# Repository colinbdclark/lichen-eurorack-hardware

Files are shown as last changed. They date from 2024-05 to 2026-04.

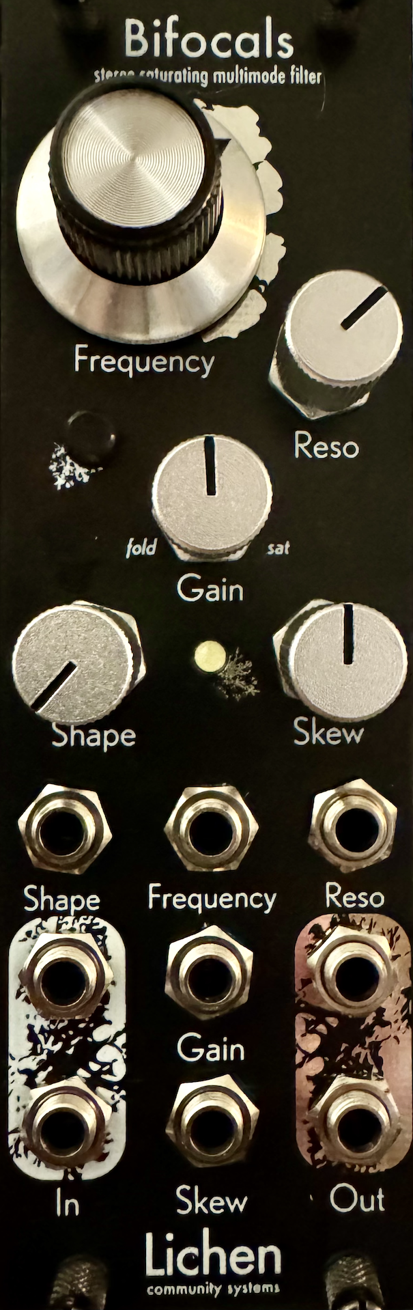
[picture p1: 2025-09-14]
bifocals-filter/bifocals photo small.png

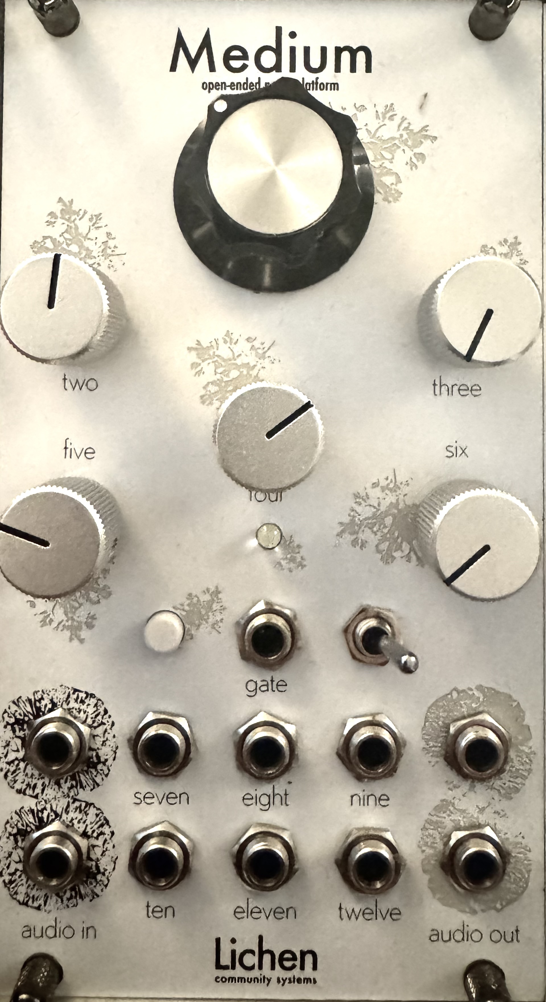
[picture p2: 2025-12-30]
lichen-medium/lichen-medium.jpg

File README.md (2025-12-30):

# Lichen Community Systems Eurorack Hardware Designs

A collection hardware schematics and PCB designs for Lichen Community Systems' experimental Eurorack modules. They were created with KiCad.

## License

These designs are Copyright 2023-5, Colin Clark. They are shared under the [Creative Commons Attribution Non-Commercial Share Alike 4.0](https://creativecommons.org/licenses/by-nc-sa/4.0/) license.

### Symbols and Footprints Library

The Lichen Kicad [symbols and footprints libraries](Lichen.pretty) were largely derived from KiCAD library symbols, and are made available under the same license:
https://kicad.org/libraries/license/

licensed under the Creative Commons CC-BY-SA 4.0 License
(https://creativecommons.org/licenses/by-sa/4.0/legalcode), with the following
exception:

To the extent that the creation of electronic designs that use
'Licensed Material' can be considered to be 'Adapted Material', then the
copyright holder waives article 3 of the license with respect to these designs
and any generated files which use data provided as part of the
'Licensed Material'.

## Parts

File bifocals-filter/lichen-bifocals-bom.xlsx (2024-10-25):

Quantity | Component | Rating | Manufacturer | Manufacturer Part Number | Vendor | Vendor Part Number | Unit Price | Currency | CAD Price | Module Price | Minimum Quantity | URL
1 | Daisy Patch Submodule |  | Electrosmith |  | Electrosmith |  | 25.2000 | USD | $34.08 | $34.08 |  | https://electro-smith.com/products/patch-submodule
2 | 2.54mm 2x5 10P pin header |  |  |  | Thonk |  | £0.114 | GBP | $0.21 | $0.42 | 10 | https://www.thonk.co.uk/shop/eurorack-diy-essentials/
6 | 2.54mm 2x5 10P pin socket |  | Sullins | PPTC052LFBN-RC | Digikey | S6105-ND | 0.5860 | CAD | $0.59 | $3.52 | 10 | https://www.digikey.ca/en/products/detail/sullins-connector-solutions/PPTC052LFBN-RC/807243
1 | 2.54mm 2x5 10P shrouded Eurorack power header |  | ULO Group | BHD10PHZT | Tayda | A-2939 | 0.1400 | USD | $0.19 | $0.19 |  | https://www.taydaelectronics.com/10-pin-box-header-connector-2-54mm.html
2 | 11mm M2 hex standoff |  | Würth | 970100244 | Digikey | 732-12845-ND | 0.5190 | CAD | $0.52 | $1.04 | 10 | https://www.digikey.ca/en/products/detail/würth-elektronik/970100244/9488549
4 | 6mm M2 screws |  | Essentra | 50M020040P006 | Digikey | 145-50M020040P006-ND | 0.0822 | CAD | $0.08 | $0.33 | 100 | https://www.digikey.ca/en/products/detail/essentra-components/50M020040P006/11639321
4 | 9mm vertical T18 potentiometer | 10K | Alpha | RD901F-40-15K-B10K | Thonk |  | £1.20 | GBP | $2.17 | $8.68 | 50 | https://www.thonk.co.uk/shop/alpha-9mm-pots-vertical-t18/
1 | 9mm vertical T18 potentiometer center detent | 10K | Alpha | RD901F-40-15K-B10K | Thonk |  | £1.82 | GBP | $3.29 | $3.29 | 10 | https://www.thonk.co.uk/shop/alpha-9mm-pots-vertical-t18/
1 | 6x2.8mm tactile switch | 250G | E-Switch | TL1105SPF250Q | Digikey | EG1862-ND | 0.3370 | CAD | $0.34 | $0.34 | 10 | https://www.digikey.ca/en/products/detail/e-switch/tl1105spf250q/271559
1 | Black switch cap |  | E-Switch | 1RBLK | Digikey | EG1882-ND | 0.2200 | CAD | $0.22 | $0.22 | 10 | https://www.digikey.ca/en/products/detail/e-switch/1RBLK/271579
1 | 3mm white LED |  |  |  | Tayda | A-2226 | 0.0400 | USD | $0.05 | $0.05 | 1 | https://www.taydaelectronics.com/led-3mm-white-water-clear-ultra-bright.html
9 | Thonkiconn mono 3.5mm audio jack |  | WQP | WQP518MA | Thonk |  | £0.27 | GBP | $0.49 | $4.41 | 100 | https://www.thonk.co.uk/shop/thonkiconn/
9 | Hex nuts for jacks |  |  |  | Thonk |  | £0.0338 | GBP | $0.06 | $0.55 | 50 | https://www.thonk.co.uk/shop/thonkiconn/
1 | Power PCB |  |  |  | JLCPCB |  | 1.3700 | USD | $1.85 | $1.85 | 5
1 | Control PCB |  |  |  | JLCPCB |  | 1.3500 | USD | $4.57 | $1.83 | 5
1 | Aluminium front panel |  |  |  | JLCPCB |  | 1.6320 | USD | $2.21 | $2.21 | 5
Total | (without shipping, tax, duty, brokerage fees etc.)
$63.00
 | PCBWay 2mm aluminum front panel black | 3.67 USD/5 CAD

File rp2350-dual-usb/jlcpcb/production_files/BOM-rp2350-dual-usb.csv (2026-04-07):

Comment | Designator | Footprint | LCSC | Quantity
1K | R16,R2,R5 | R_0402_1005Metric | C11702 | 3
100nF | C21 | C_0603 | C14663 | 1
15pF | C4,C5 | C_0402_1005Metric_small_pads | C1548 | 2
Conn_01x03_MountingPin | J1 | JST_SH_SM03B-SRSS-TB_1x03-1MP_P1.00mm_Horizontal | C160403 | 1
USB_C_Receptacle_USB2.0_16P | J2,J3 | USB_C_Receptacle_HRO_TYPE-C-31-M-12_Overhanging | C165948 | 2
4.7uF | C8 | C_0805 | C1779 | 1
12MHz | Y1 | Crystal_SMD_3225-4Pin_3.2x2.5mm | C20625731 | 1
Yellow | D1 | LED_0805_2012Metric_Pad1.15x1.40mm_HandSolder | C2296 | 1
Green | D2 | LED_0805_2012Metric_Pad1.15x1.40mm_HandSolder | C2297 | 1
5.1K | R7,R8 | R_0603 | C23186 | 2
4.7uF | C10,C3,C7,C9 | C_0402_1005Metric_small_pads | C23733 | 4
10R | R12 | R_0402_1005Metric | C25077 | 1
220R | R13,R14 | R_0402_1005Metric | C25091 | 2
27R | R17,R18,R3,R4 | R_0402_1005Metric | C25100 | 4
33R | R1,R11 | R_0402_1005Metric | C25105 | 2
470R | R15 | R_0402_1005Metric | C25117 | 1
100K | R19 | R_0402_1005Metric | C25741 | 1
1.5K | R6 | R_0402_1005Metric | C25867 | 1
1uF | C2 | C_0805 | C28323 | 1
100nF | C1,C11,C12,C13,C14,C15,C16,C17,C18,C19,C20,C6 | C_0402_1005Metric_small_pads | C307331 | 12
RP2354_60QFN | U2 | RP2350-QFN-60-1EP_7x7_P0.4mm_EP3.4x3.4mm_ThermalVias | C41378174 | 1
3.3uH | L1 | L_pol_2016 | C42411119 | 1
LDL1117-3.3 | U1 | SOT-223-3_TabPin2 | C435835 | 1
HCPL-0631 | U5 | SOIC-8_3.9x4.9mm_P1.27mm | C43949 | 1
TPS25810RVC | U6 | Texas_RVC0020A_WQFN-20-1EP_3x4mm_P0.5mm_EP1.6x2.6mm_ThermalVias | C473913 | 1
1P1T Switch | SW1 | SW_SPST_TS-1088-xR020 | C720477 | 1
USBLC6-2SC6 | U3,U4 | SOT-23-6 | C7519 | 2
TRS | J4,J5 | Jack_3.5mm_KoreanHropartsElec_PJ-320D-4A_Horizontal_Overhanging | C95562 | 2
47uF | C23,C24,C25 | C_1206_3216Metric | C96123 | 3
10uF | C22 | C_0603 | C96446 | 1

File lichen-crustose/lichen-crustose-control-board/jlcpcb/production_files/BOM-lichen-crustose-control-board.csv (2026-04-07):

Comment | Designator | Footprint | LCSC | Quantity
33pF C0G | C3,C4,C5,C6 | C_0603 | C1663 | 4
330pF C0G | C10,C7,C8,C9 | C_0603 | C1664 | 4
1K | R15,R16,R33,R34 | R_0603 | C21190 | 4
5.1K | R10,R13,R14,R9 | R_0603 | C23186 | 4
100K | R1,R17,R18,R19,R2,R20,R21,R22,R23,R24,R25,R26,R27,R28,R29,R3,R30,R5,R6,R7,R8 | R_0603 | C25803 | 21
10K | R11,R12,R31,R32,R35,R36,R37,R38,R39,R4,R40 | R_0603 | C25804 | 11
100nF | C11,C12,C13,C14,C16,C17,C18,C19 | C_0402_1005Metric_small_pads | C307331 | 8
100nF Film | C1,C2 | C_1210 | C569766 | 2
TL074 | OP1,OP2,OP3,OP4 | SOIC-14_3.9x8.7mm_P1.27mm | C6964 | 4

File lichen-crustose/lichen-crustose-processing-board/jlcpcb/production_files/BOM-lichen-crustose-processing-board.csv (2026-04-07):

Comment | Designator | Footprint | LCSC | Quantity
FerriteBead_0603_2A | L1,L2 | R_0603 | C14709 | 2
39K | R1 | R_0603 | C23153 | 1
10K | R2 | R_0603 | C25804 | 1
10uF | C1,C2,C4,C5,C6,C7 | C_0805 | C440198 | 6
Schottky | D1,D2 | D_SMA_Handsoldering | C8678 | 2

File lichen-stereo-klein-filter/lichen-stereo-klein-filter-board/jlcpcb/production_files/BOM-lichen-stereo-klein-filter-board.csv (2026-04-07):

Comment | Designator | Footprint | LCSC | Quantity
10uF | C15,C16,C27,C28,C29,C30 | C_1206_3216Metric | C13585 | 6
FerriteBead_0603_2A | L1,L2 | R_0603 | C14709 | 2
1K | R16,R26,R33,R42 | R_0603 | C21190 | 4
15K | R50,R8 | R_0603 | C22809 | 2
27K | R13,R54 | R_0603 | C22967 | 2
2K | R24,R40 | R_0603 | C22975 | 2
68K | R10,R17,R51,R52 | R_0603 | C23231 | 4
100K | R1,R12,R18,R34,R49,R53 | R_0603 | C25803 | 6
10K | R55,R56 | R_0603 | C25804 | 2
100nF | C17,C18,C19,C20,C21,C22,C23,C24,C25,C26 | C_0402_1005Metric_small_pads | C307331 | 10
33K | R19,R20,R22,R25,R29,R30,R31,R32,R35,R36,R39,R41,R45,R46,R47,R48 | R_0603 | C4216 | 16
MMBD4148TW | D1,D2,D3,D4,D5,D6 | SOT-363_SC-70-6 | C5240652 | 6
1nF | C10,C11,C13,C14,C2,C3,C4,C6,C7,C9 | C_0805 | C569826 | 10
TL072 | U6 | SOIC-8_3.9x4.9mm_P1.27mm | C6961 | 1
TL074 | U2,U3,U4,U5 | SOIC-14_3.9x8.7mm_P1.27mm | C6964 | 4
02x07 Pins | J8 | PinHeader_2x07_P2.54mm_Vertical_SMD | C84004 | 1
Schottky | D7,D8 | D_SMA_Handsoldering | C8678 | 2

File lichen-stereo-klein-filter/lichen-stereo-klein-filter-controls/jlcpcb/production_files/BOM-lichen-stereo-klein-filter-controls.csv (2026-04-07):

Comment | Designator | Footprint | LCSC | Quantity
1K | R27,R43,R7 | R_0603 | C21190 | 3
12K | R11 | R_0603 | C22790 | 1
27K | R2 | R_0603 | C22967 | 1
2K | R23,R38 | R_0603 | C22975 | 2
100K | R14,R21,R28,R37,R44 | R_0603 | C25803 | 5
10K | R15,R3,R4,R5,R6,R9 | R_0603 | C25804 | 6
100nF | C31,C32 | C_0402_1005Metric_small_pads | C307331 | 2
TL074 | U1 | SOIC-14_3.9x8.7mm_P1.27mm | C6964 | 1
02x07 Socket | J7 | PinSocket_2x07_P2.54mm_Vertical_SMD | C84005 | 1

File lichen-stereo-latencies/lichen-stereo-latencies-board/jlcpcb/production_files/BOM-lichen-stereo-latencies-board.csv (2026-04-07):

Comment | Designator | Footprint | LCSC | Quantity
1K | R15,R19 | R_0402_1005Metric | C11702 | 2
FerriteBead_0603_2A | L1,L2 | R_0603 | C14709 | 2
33pF C0G | C5,C6 | C_0603 | C1663 | 2
100K | R1,R10,R11,R12,R13,R14,R16,R17,R18,R2,R20,R3,R4,R5,R6,R7,R8,R9 | R_0402_1005Metric | C25741 | 18
10K | R21 | R_0402_1005Metric | C25744 | 1
12K | R22 | R_0402_1005Metric | C25752 | 1
10uF | C7,C8 | C_0805 | C440198 | 2
TL074 | U1,U3,U5,U7 | SOIC-14_3.9x8.7mm_P1.27mm | C6964 | 4
Schottky | D1,D2 | D_SMA_Handsoldering | C8678 | 2

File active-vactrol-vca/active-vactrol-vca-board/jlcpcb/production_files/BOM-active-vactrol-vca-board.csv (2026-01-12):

Comment | Designator | Footprint | LCSC | Quantity
FerriteBead_0603_2A | L1,L2 | R_0603 | C14709 | 2
33pF C0G | C5,C8 | C_0603 | C1663 | 2
1k_0603 | R18,R9 | R_0603 | C21190 | 2
1R | R6,R7 | R_0603 | C22936 | 2
100k_0603 | R1,R10,R11,R12,R13,R17,R19,R2,R20,R3,R4,R5,R8 | R_0603 | C25803 | 13
10uF_0805_25V | C1,C2 | C_0805 | C440198 | 2
22uF_0805_25V | C3,C6 | C_0805 | C45783 | 2
AMS1117-5.0 | U7 | SOT-223-3_TabPin2 | C6187 | 1
TL072 | U1,U2,U3,U4 | SOIC-8_3.9x4.9mm_P1.27mm | C6961 | 4
Schottky | D1,D2 | D_SMA_Handsoldering | C8678 | 2

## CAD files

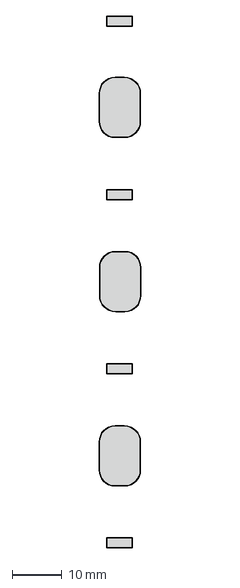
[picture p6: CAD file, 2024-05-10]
lichen-usb-extender/2 hp usb extender.dxf
8.35 x 107.1 mm

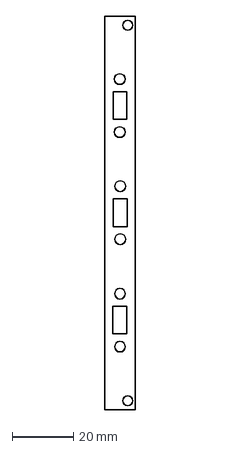
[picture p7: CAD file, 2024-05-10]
lichen-usb-extender/edge cuts - 2 hp usb extender.dxf
10.00 x 128.5 mm

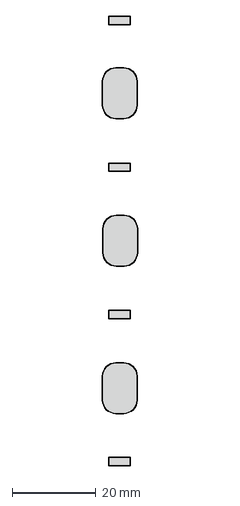
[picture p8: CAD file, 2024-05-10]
lichen-usb-extender/silkscreen - 2 hp usb extender.dxf
8.35 x 107.1 mm

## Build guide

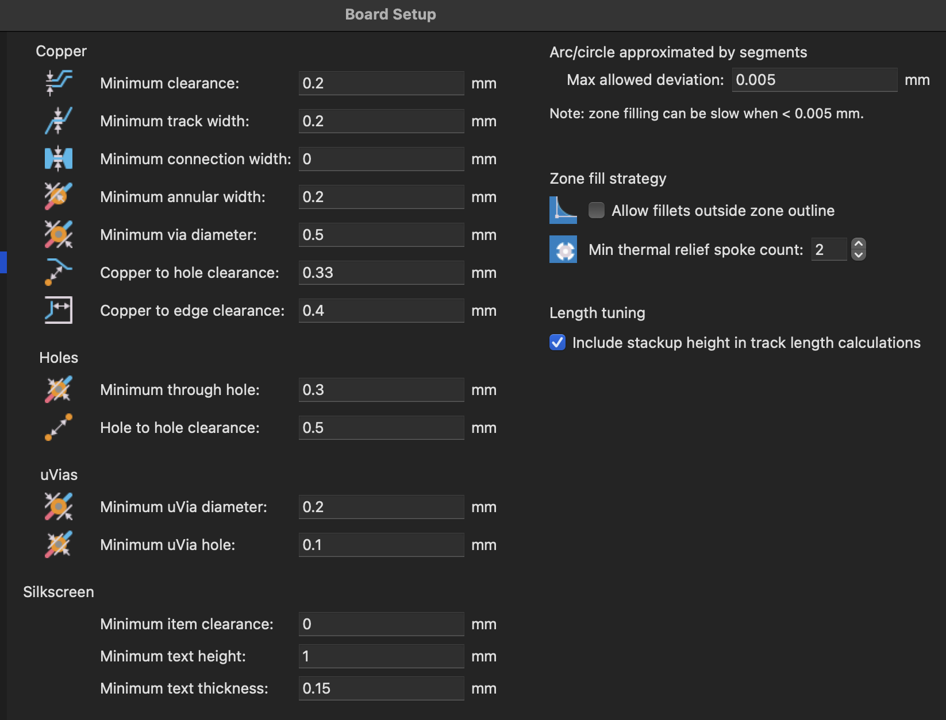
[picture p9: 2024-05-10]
kicad-setup/Board Setup Constraints.png

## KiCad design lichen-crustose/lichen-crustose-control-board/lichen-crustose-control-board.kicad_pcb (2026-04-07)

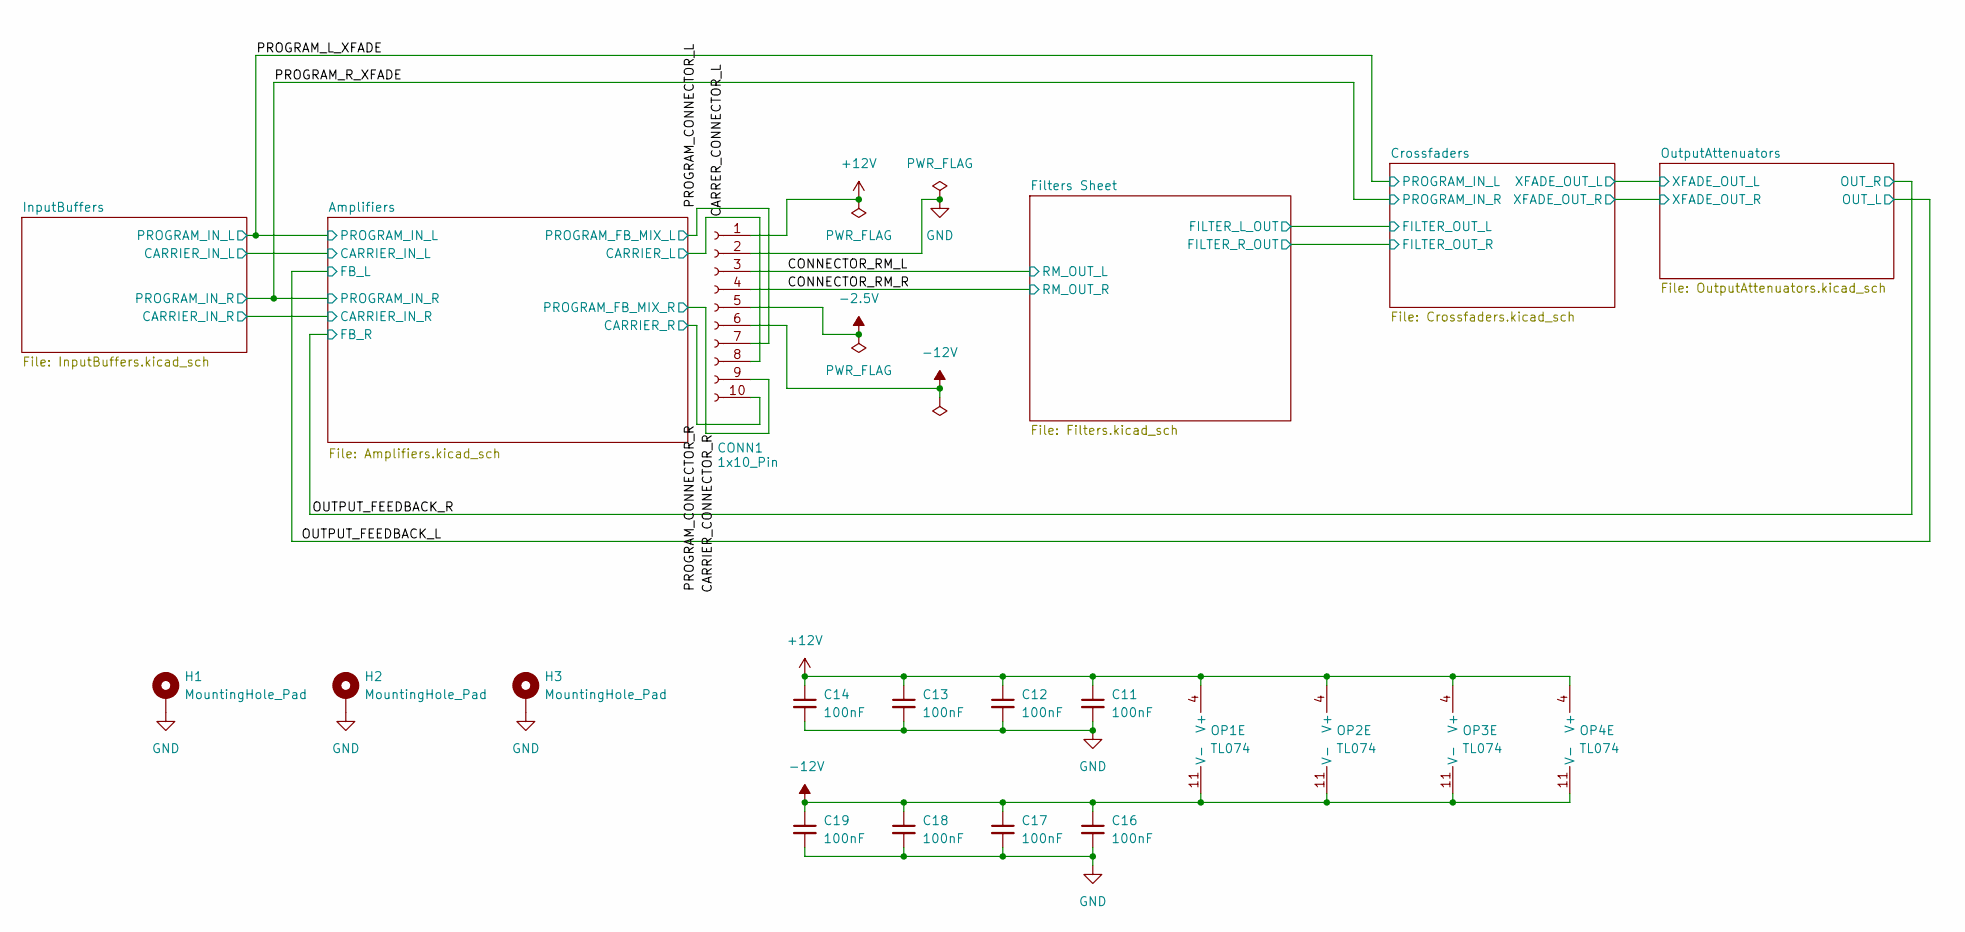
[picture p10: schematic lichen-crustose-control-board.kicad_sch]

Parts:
C11, C12, C13, C14, C16, C17, C18, C19: 100nF; C_0402_1005Metric_small_pads; Part Number CL05B104KB54PNC; LCSC C307331
CONN1: 1x10_Pin; PinHeader_1x10_P2.54mm_Vertical
H1, H2, H3: MountingHole_Pad; MountingHole_2.2mm_M2_Pad
OP1, OP2, OP3, OP4: TL074; SOIC-14_3.9x8.7mm_P1.27mm; Part Number TL074IDR; LCSC C6964

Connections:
+12V: C11.1, C12.1, C13.1, C14.1, CONN1.1, OP1.4 (V+), OP2.4 (V+), OP3.4 (V+), OP4.4 (V+)
-2.5V: CONN1.5; also elsewhere on the board
-12V: C16.1, C17.1, C18.1, C19.1, CONN1.6, OP1.11 (V-), OP2.11 (V-), OP3.11 (V-), OP4.11 (V-)
/CARRER_CONNECTOR_L: CONN1.8; also elsewhere on the board
/CARRIER_CONNECTOR_R: CONN1.9; also elsewhere on the board
/CONNECTOR_RM_L: CONN1.3; also elsewhere on the board
/CONNECTOR_RM_R: CONN1.4; also elsewhere on the board
/PROGRAM_CONNECTOR_L: CONN1.7; also elsewhere on the board
/PROGRAM_CONNECTOR_R: CONN1.10; also elsewhere on the board
GND: C11.2, C12.2, C13.2, C14.2, C16.2, C17.2, C18.2, C19.2, CONN1.2, H1.1, H2.1, H3.1; also elsewhere on the board

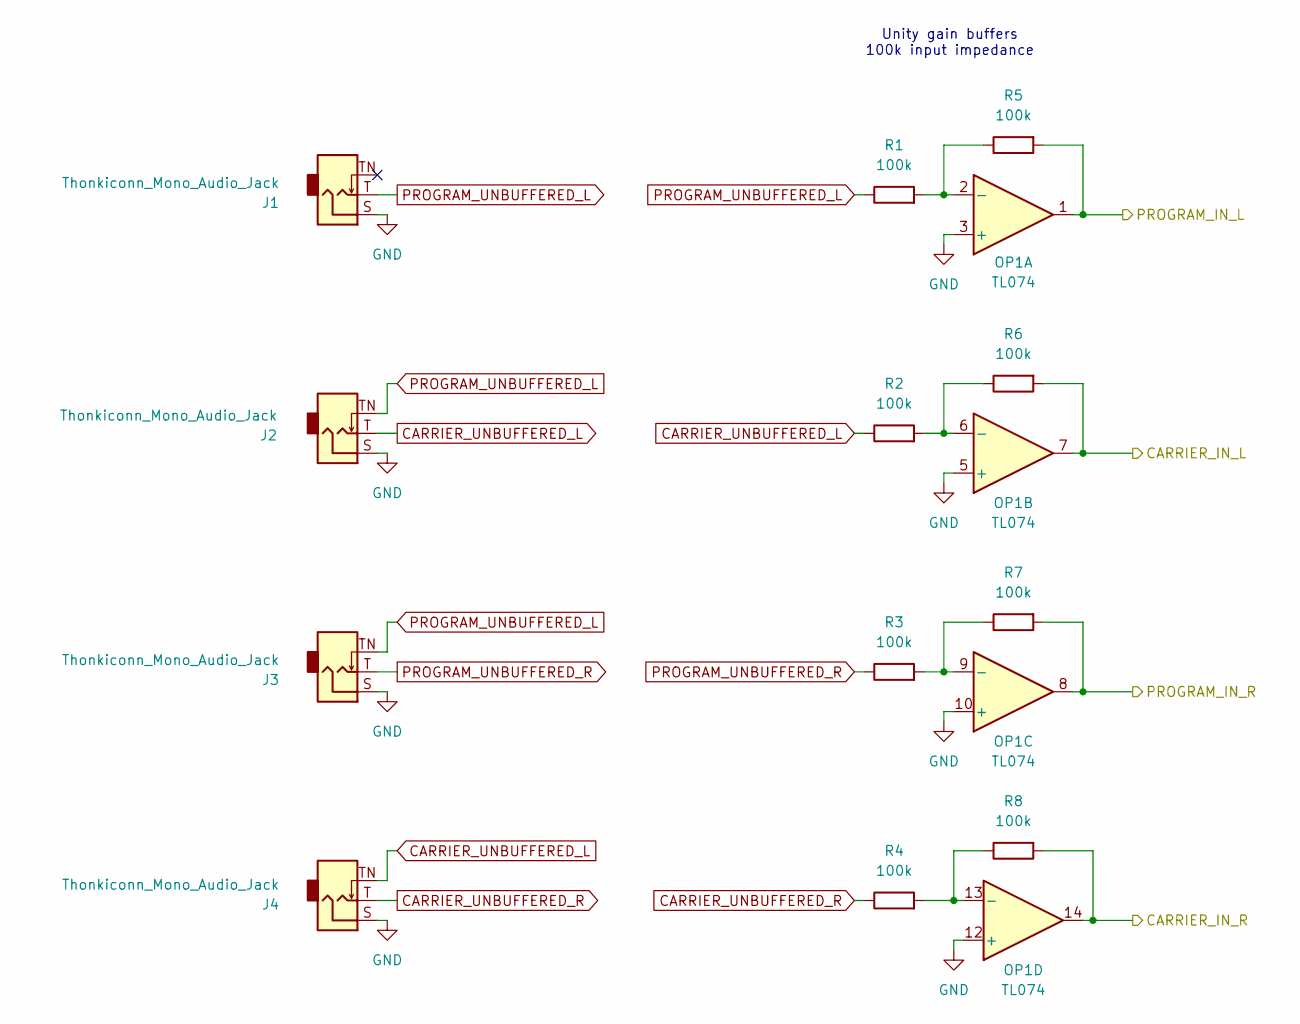
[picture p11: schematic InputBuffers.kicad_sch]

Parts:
J1, J2, J3, J4: Thonkiconn_Mono_Audio_Jack; Audio_Jack_Thonkiconn_Mono; Part Number WQP518MA/PJ398SM
OP1: TL074; SOIC-14_3.9x8.7mm_P1.27mm; Part Number TL074IDR; LCSC C6964
R1, R2, R3, R4, R5, R6, R7: 100K; R_0603; Part Number 0603WAF1003T5E; LCSC C25803
R8: 100K; R_0603; Part Number 0603WAF1003T5E; JLCPCB ID C25803

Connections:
/Amplifiers/CARRIER_IN_L: OP1.7, R6.2; also elsewhere on the board
/Amplifiers/CARRIER_IN_R: OP1.14, R8.2; also elsewhere on the board
/PROGRAM_L_XFADE: OP1.1, R5.2; also elsewhere on the board
/PROGRAM_R_XFADE: OP1.8, R7.2; also elsewhere on the board
CARRIER_UNBUFFERED_L: J2.T, J4.TN, R2.1
CARRIER_UNBUFFERED_R: J4.T, R4.1
GND: J1.S, J2.S, J3.S, J4.S, OP1.3 (+), OP1.5 (+), OP1.10 (+), OP1.12 (+); also elsewhere on the board
unnamed: OP1.2 (-), R1.2, R5.1
unnamed: OP1.6 (-), R2.2, R6.1
unnamed: OP1.9 (-), R3.2, R7.1
unnamed: OP1.13 (-), R4.2, R8.1
PROGRAM_UNBUFFERED_L: J1.T, J2.TN, J3.TN, R1.1
PROGRAM_UNBUFFERED_R: J3.T, R3.1

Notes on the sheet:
Unity gain buffers 100k input impedance

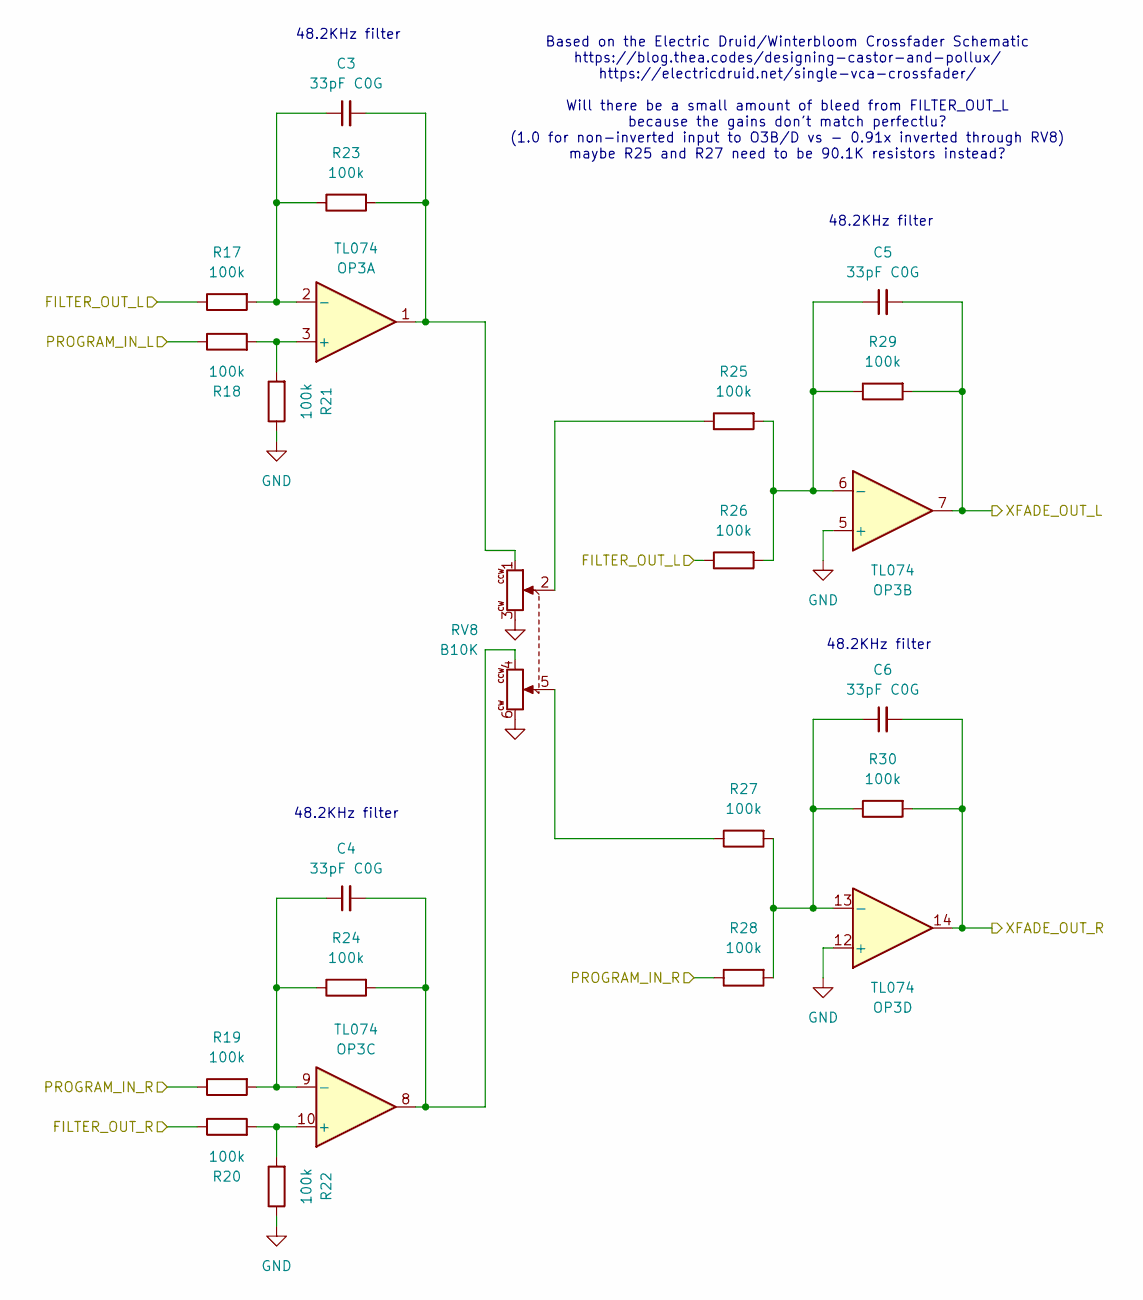
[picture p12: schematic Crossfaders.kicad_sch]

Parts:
C3, C4, C5, C6: 33pF C0G; C_0603; Part Number CL10C330JB8NNNC; LCSC C1663
OP3: TL074; SOIC-14_3.9x8.7mm_P1.27mm; Part Number TL074IDR; LCSC C6964
R17, R18, R19, R20, R21, R22, R23, R24, R25, R26, R27, R28, R29, R30: 100K; R_0603; Part Number 0603WAF1003T5E; LCSC C25803
RV8: B10K; Potentiometer_Alpha_RD902F-40-00D_Dual_Vertical; Part Number RD90F-40

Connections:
/Crossfaders/FILTER_OUT_L: R17.1, R26.1; also elsewhere on the board
/Crossfaders/FILTER_OUT_R: R20.1; also elsewhere on the board
/Crossfaders/XFADE_OUT_L: C5.2, OP3.7, R29.2; also elsewhere on the board
/Crossfaders/XFADE_OUT_R: C6.2, OP3.14, R30.2; also elsewhere on the board
/PROGRAM_L_XFADE: R18.1; also elsewhere on the board
/PROGRAM_R_XFADE: R19.1, R28.1; also elsewhere on the board
GND: OP3.5 (+), OP3.12 (+), R21.1, R22.1, RV8.3, RV8.6; also elsewhere on the board
unnamed: C3.2, OP3.1, R23.2, RV8.1
unnamed: C4.2, OP3.8, R24.2, RV8.4
unnamed: OP3.3 (+), R18.2, R21.2
unnamed: C3.1, OP3.2 (-), R17.2, R23.1
unnamed: C5.1, OP3.6 (-), R25.2, R26.2, R29.1
unnamed: OP3.10 (+), R20.2, R22.2
unnamed: C4.1, OP3.9 (-), R19.2, R24.1
unnamed: C6.1, OP3.13 (-), R27.2, R28.2, R30.1
unnamed: R25.1, RV8.2
unnamed: R27.1, RV8.5

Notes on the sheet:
Based on the Electric Druid/Winterbloom Crossfader Schematic https://blog.thea.codes/designing-castor-and-pollux/ https://electricdruid.net/single-vca-crossfader/ Will there be a small amount of bleed from FILTER_OUT_L because the gains don't match perfectlu? (1.0 for non-inverted input to O3B/D vs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
48.2KHz filter

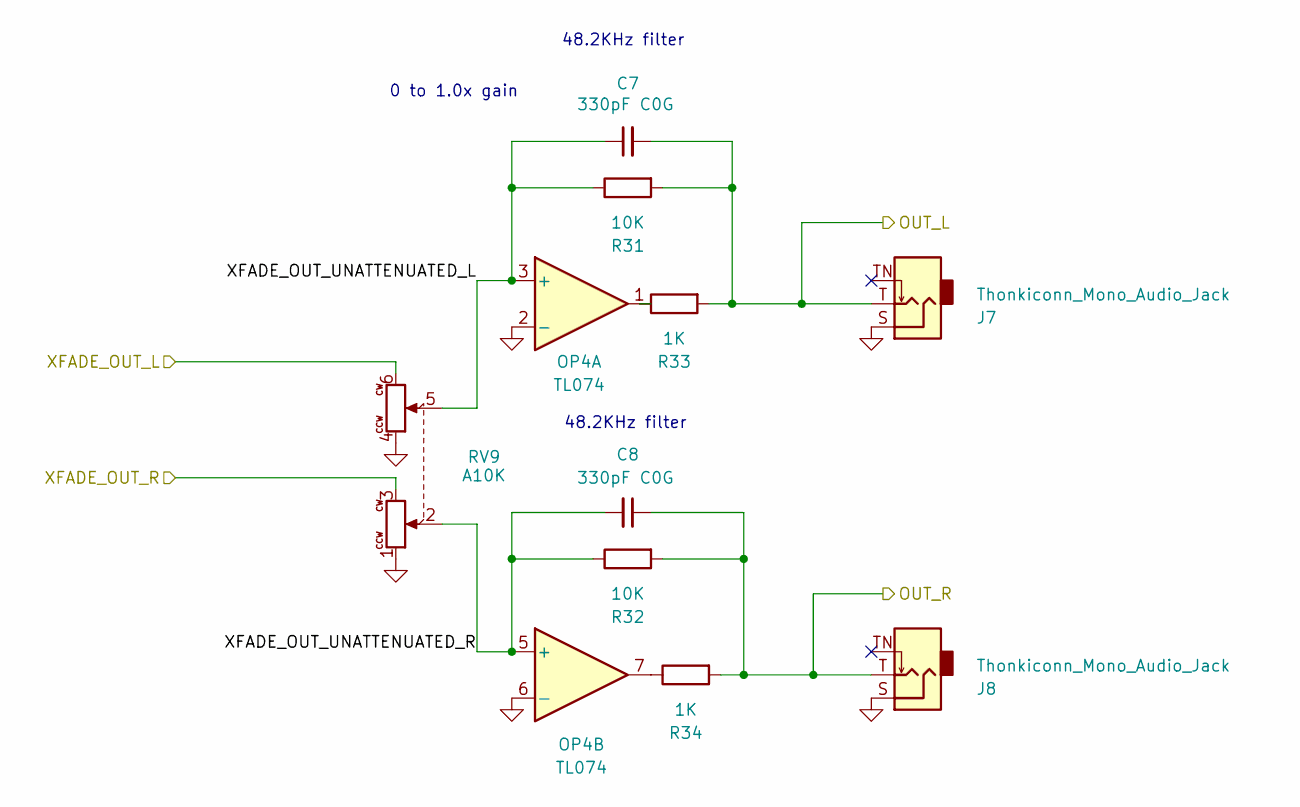
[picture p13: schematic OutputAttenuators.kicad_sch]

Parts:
C7, C8: 330pF C0G; C_0603; Part Number CL10C331JB8NNNC; LCSC C1664
J7, J8: Thonkiconn_Mono_Audio_Jack; Audio_Jack_Thonkiconn_Mono; Part Number WQP518MA/PJ398SM
OP4: TL074; SOIC-14_3.9x8.7mm_P1.27mm; Part Number TL074IDR; LCSC C6964
R31, R32: 10K; R_0603; Part Number 0603WAF1002T5E; LCSC C25804
R33, R34: 1K; R_0603; Part Number 0603WAF1001T5E; LCSC C21190
RV9: A10K; Potentiometer_Alpha_RD902F-40-00D_Dual_Vertical; Part Number RD90F-40

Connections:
/Crossfaders/XFADE_OUT_L: RV9.6; also elsewhere on the board
/Crossfaders/XFADE_OUT_R: RV9.3; also elsewhere on the board
/OUTPUT_FEEDBACK_L: C7.2, J7.T, R31.2, R33.2; also elsewhere on the board
/OUTPUT_FEEDBACK_R: C8.1, J8.T, R32.2, R34.2; also elsewhere on the board
/OutputAttenuators/XFADE_OUT_UNATTENUATED_L: C7.1, OP4.3 (+), R31.1, RV9.5
/OutputAttenuators/XFADE_OUT_UNATTENUATED_R: C8.2, OP4.5 (+), R32.1, RV9.2
GND: J7.S, J8.S, OP4.2 (-), OP4.6 (-), RV9.1, RV9.4; also elsewhere on the board
unnamed: OP4.1, R33.1
unnamed: OP4.7, R34.1

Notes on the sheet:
48.2KHz filter
0 to 1.0x gain

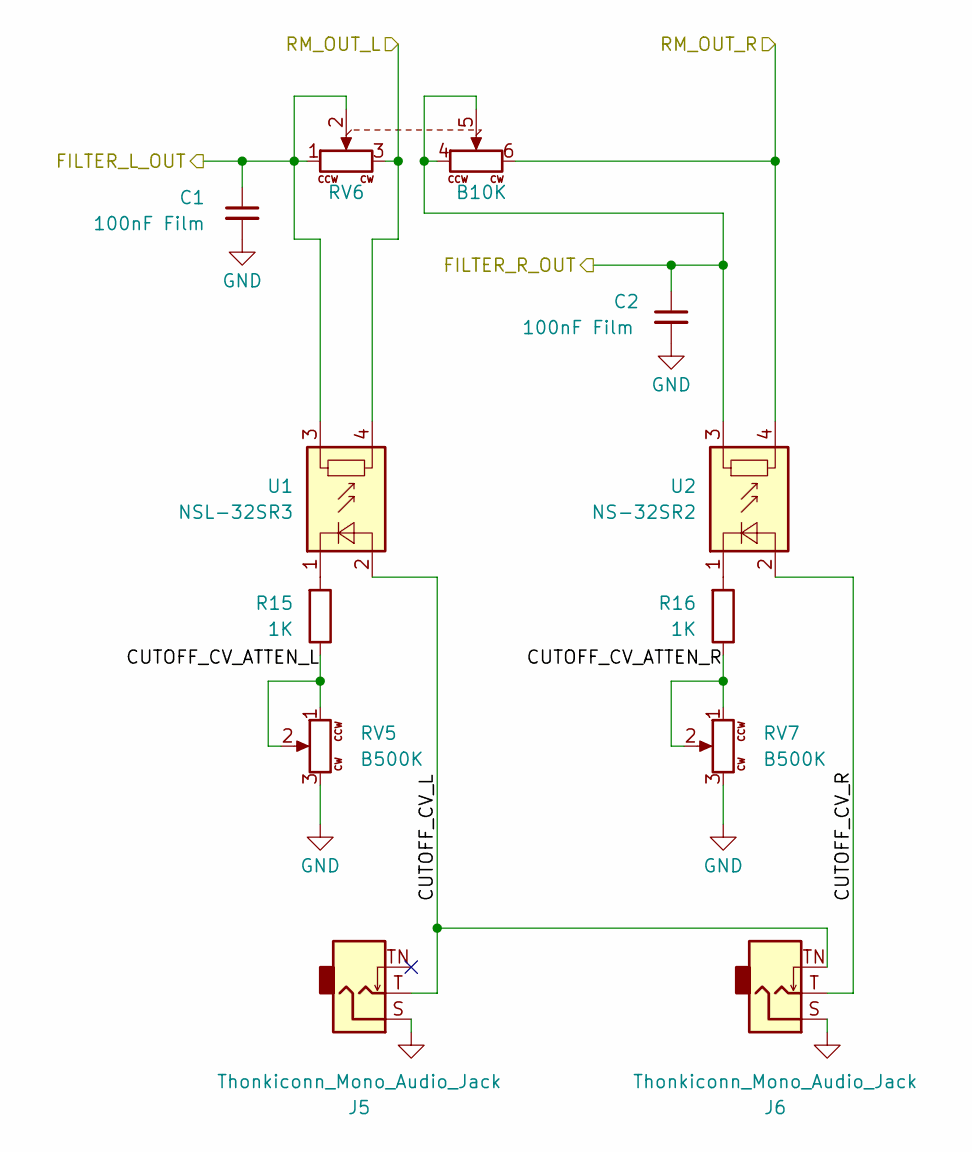
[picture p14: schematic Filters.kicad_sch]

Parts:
C1, C2: 100nF Film; C_1210; Part Number ECHU1C104GX5; LCSC C569766
J5, J6: Thonkiconn_Mono_Audio_Jack; Audio_Jack_Thonkiconn_Mono; Part Number WQP518MA/PJ398SM
R15, R16: 1K; R_0603; Part Number 0603WAF1001T5E; LCSC C21190
RV5, RV7: B500K; Potentiometer_Alpha_RD901_Eurorack; Part Number RD901F-40
RV6: B10K; Potentiometer_Alpha_RD902F-40-00D_Dual_Vertical; Part Number RD90F-40
U1: NSL-32SR3; NSL-32
U2: NS-32SR2; NSL-32

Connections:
/CONNECTOR_RM_L: RV6.3, U1.4; also elsewhere on the board
/CONNECTOR_RM_R: RV6.6, U2.4; also elsewhere on the board
/Crossfaders/FILTER_OUT_L: C1.1, RV6.1, RV6.2, U1.3; also elsewhere on the board
/Crossfaders/FILTER_OUT_R: C2.1, RV6.4, RV6.5, U2.3; also elsewhere on the board
/Filters Sheet/CUTOFF_CV_ATTEN_L: R15.1, RV5.1, RV5.2
/Filters Sheet/CUTOFF_CV_ATTEN_R: R16.1, RV7.1, RV7.2
/Filters Sheet/CUTOFF_CV_L: J5.T, J6.TN, U1.2 (+)
/Filters Sheet/CUTOFF_CV_R: J6.T, U2.2 (+)
GND: C1.2, C2.2, J5.S, J6.S, RV5.3, RV7.3; also elsewhere on the board
unnamed: R15.2, U1.1 (-)
unnamed: R16.2, U2.1 (-)

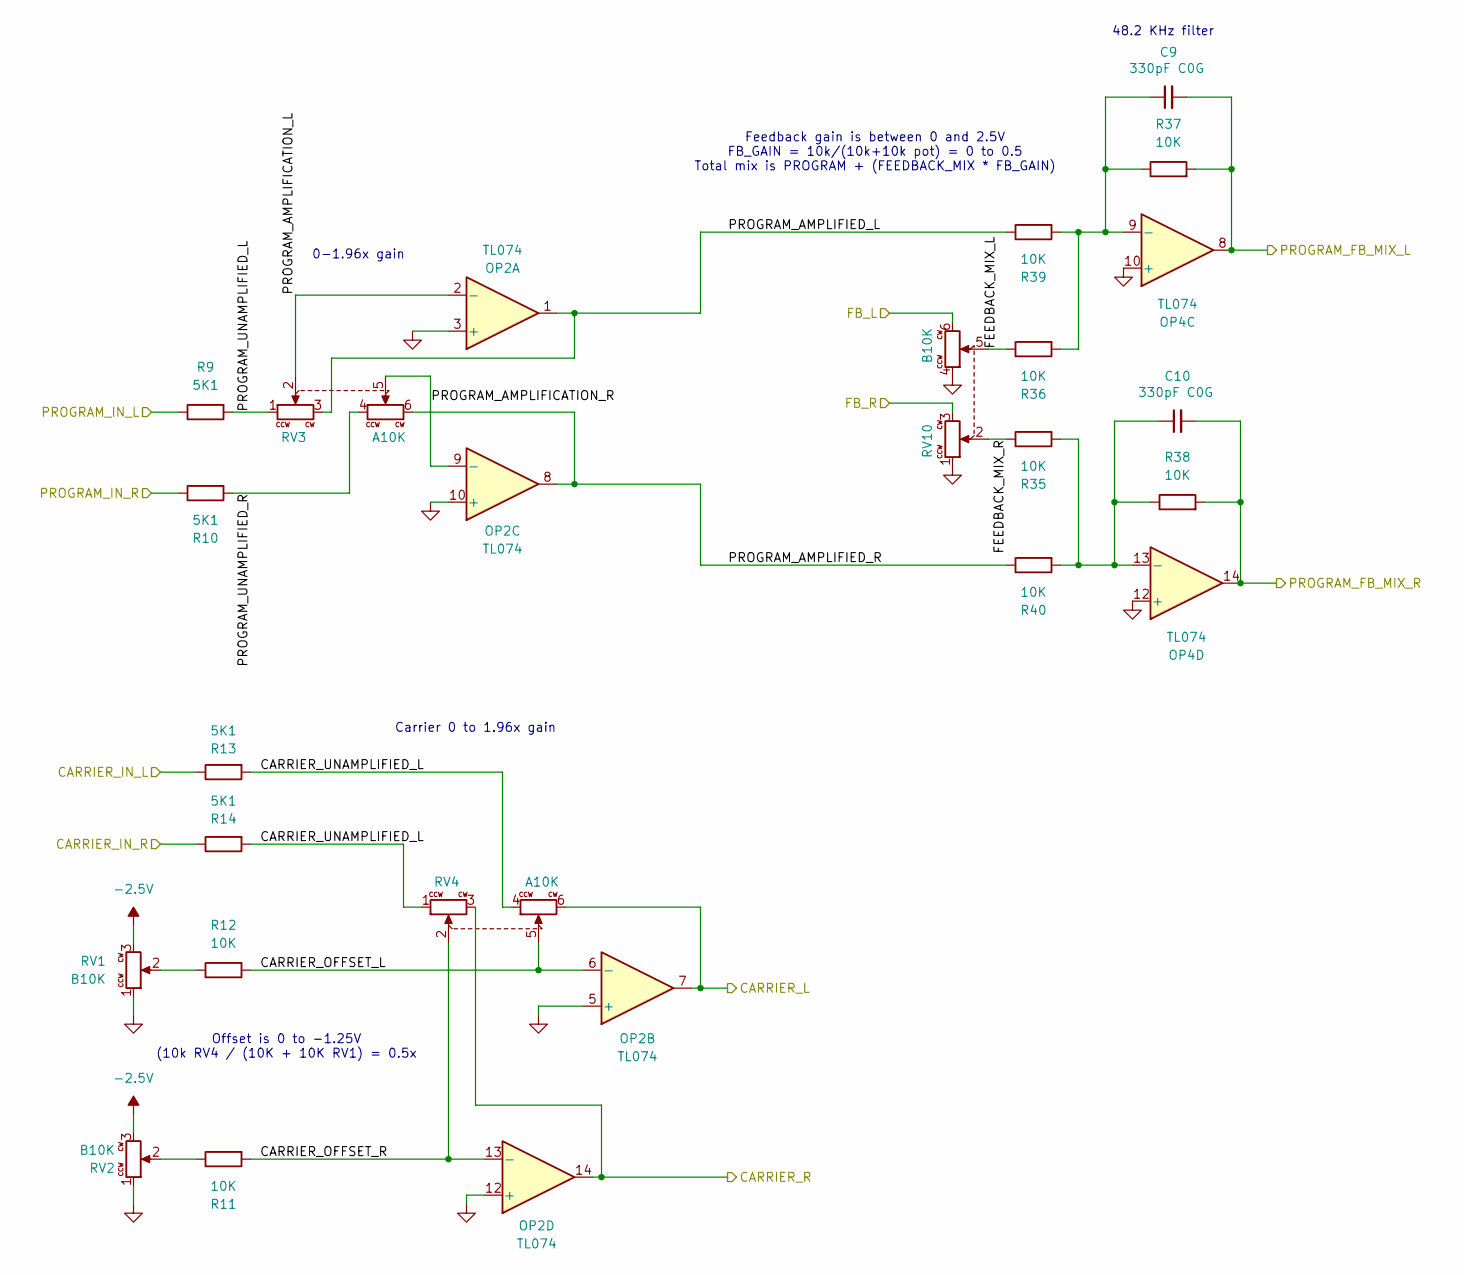
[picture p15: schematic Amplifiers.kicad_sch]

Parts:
C9, C10: 330pF C0G; C_0603; Part Number CL10C331JB8NNNC; LCSC C1664
OP2, OP4: TL074; SOIC-14_3.9x8.7mm_P1.27mm; Part Number TL074IDR; LCSC C6964
R9, R10, R13, R14: 5.1K; R_0603; Part Number 0603WAF5101T5E; LCSC C23186
R11, R12, R35, R36, R37, R38, R39, R40: 10K; R_0603; Part Number 0603WAF1002T5E; LCSC C25804
RV1, RV2: B10K; Potentiometer_Alpha_RD901_Eurorack; Part Number RD901F-40
RV3, RV4: A10K; Potentiometer_Alpha_RD902F-40-00D_Dual_Vertical; Part Number RD90F-40
RV10: B10K; Potentiometer_Alpha_RD902F-40-00D_Dual_Vertical; Part Number RD90F-40

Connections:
-2.5V: RV1.3, RV2.3; also elsewhere on the board
/Amplifiers/CARRIER_IN_L: R13.1; also elsewhere on the board
/Amplifiers/CARRIER_IN_R: R14.1; also elsewhere on the board
/Amplifiers/CARRIER_OFFSET_L: OP2.6 (-), R12.2, RV4.5
/Amplifiers/CARRIER_OFFSET_R: OP2.13 (-), R11.2, RV4.2
/Amplifiers/CARRIER_UNAMPLIFIED_L: R13.2, R14.2, RV4.1, RV4.4
/Amplifiers/FEEDBACK_MIX_L: R36.1, RV10.5
/Amplifiers/FEEDBACK_MIX_R: R35.1, RV10.2
/Amplifiers/PROGRAM_AMPLIFICATION_L: OP2.2 (-), RV3.2
/Amplifiers/PROGRAM_AMPLIFICATION_R: OP2.9 (-), RV3.5
/Amplifiers/PROGRAM_AMPLIFIED_L: OP2.1, R39.1, RV3.3
/Amplifiers/PROGRAM_AMPLIFIED_R: OP2.8, R40.1, RV3.6
/Amplifiers/PROGRAM_UNAMPLIFIED_L: R9.2, RV3.1
/Amplifiers/PROGRAM_UNAMPLIFIED_R: R10.2, RV3.4
/CARRER_CONNECTOR_L: OP2.7, RV4.6; also elsewhere on the board
/CARRIER_CONNECTOR_R: C10.2, OP4.14, R38.2; also elsewhere on the board
/OUTPUT_FEEDBACK_L: RV10.6; also elsewhere on the board
/OUTPUT_FEEDBACK_R: RV10.3; also elsewhere on the board
/PROGRAM_CONNECTOR_L: C9.2, OP4.8, R37.2; also elsewhere on the board
/PROGRAM_CONNECTOR_R: OP2.14, RV4.3; also elsewhere on the board
/PROGRAM_L_XFADE: R9.1; also elsewhere on the board
/PROGRAM_R_XFADE: R10.1; also elsewhere on the board
GND: OP2.3 (+), OP2.5 (+), OP2.10 (+), OP2.12 (+), OP4.10 (+), OP4.12 (+), RV1.1, RV2.1, RV10.1, RV10.4; also elsewhere on the board
unnamed: C9.1, OP4.9 (-), R36.2, R37.1, R39.2
unnamed: C10.1, OP4.13 (-), R35.2, R38.1, R40.2
unnamed: R11.1, RV2.2
unnamed: R12.1, RV1.2

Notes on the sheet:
Offset is 0 to -1.25V (10k RV4 / (10K + 10K RV1) = 0.5x
Feedback gain is between 0 and 2.5V FB_GAIN = 10k/(10k+10k pot) = 0 to 0.5 Total mix is PROGRAM + (FEEDBACK_MIX * FB_GAIN)
48.2 KHz filter
0-1.96x gain
Carrier 0 to 1.96x gain

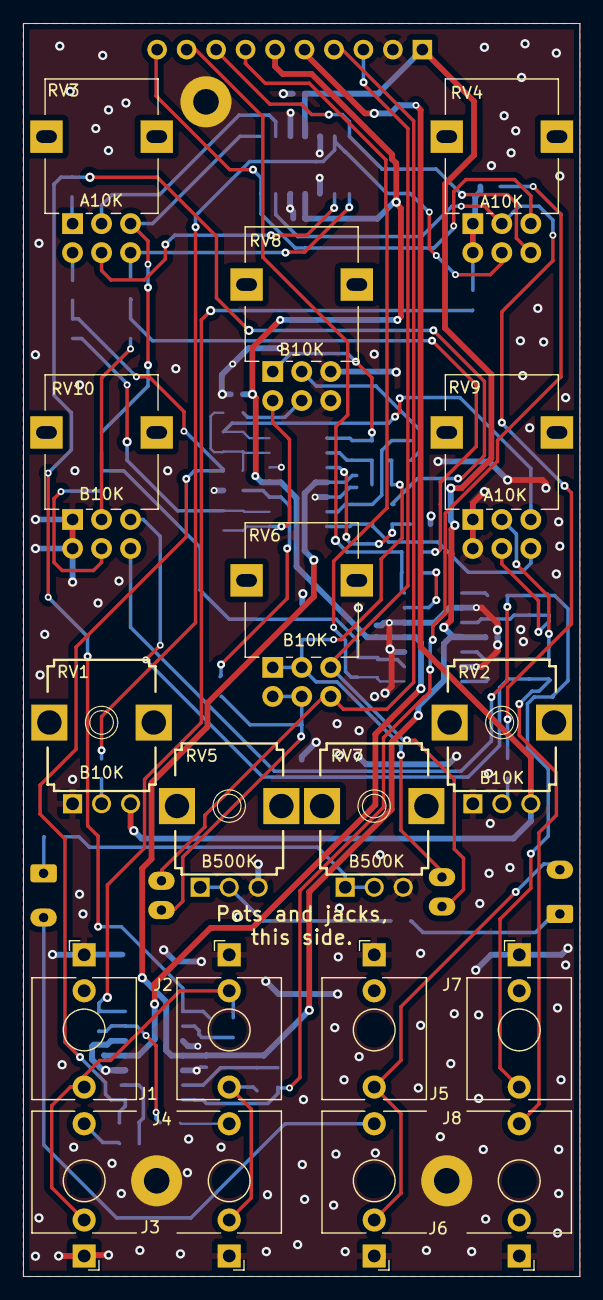
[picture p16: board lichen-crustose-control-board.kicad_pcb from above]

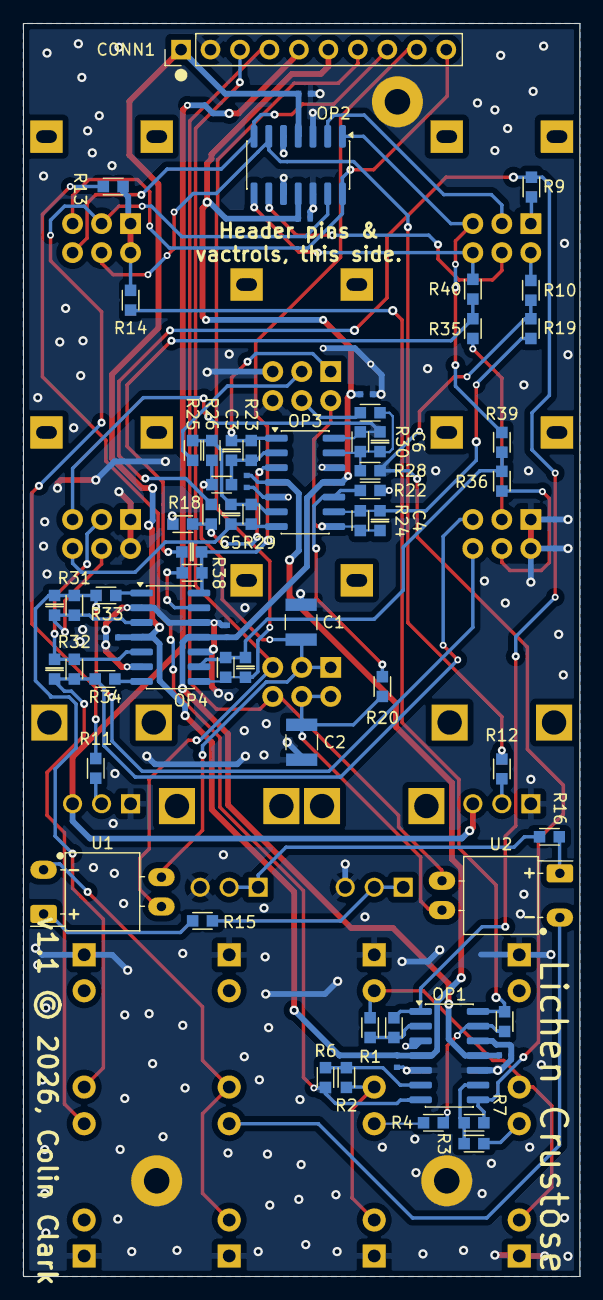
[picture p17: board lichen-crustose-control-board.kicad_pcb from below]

Board: 2 copper layers, 48.0 x 108.0 mm, 86 parts (67 on the bottom side), 63 nets.

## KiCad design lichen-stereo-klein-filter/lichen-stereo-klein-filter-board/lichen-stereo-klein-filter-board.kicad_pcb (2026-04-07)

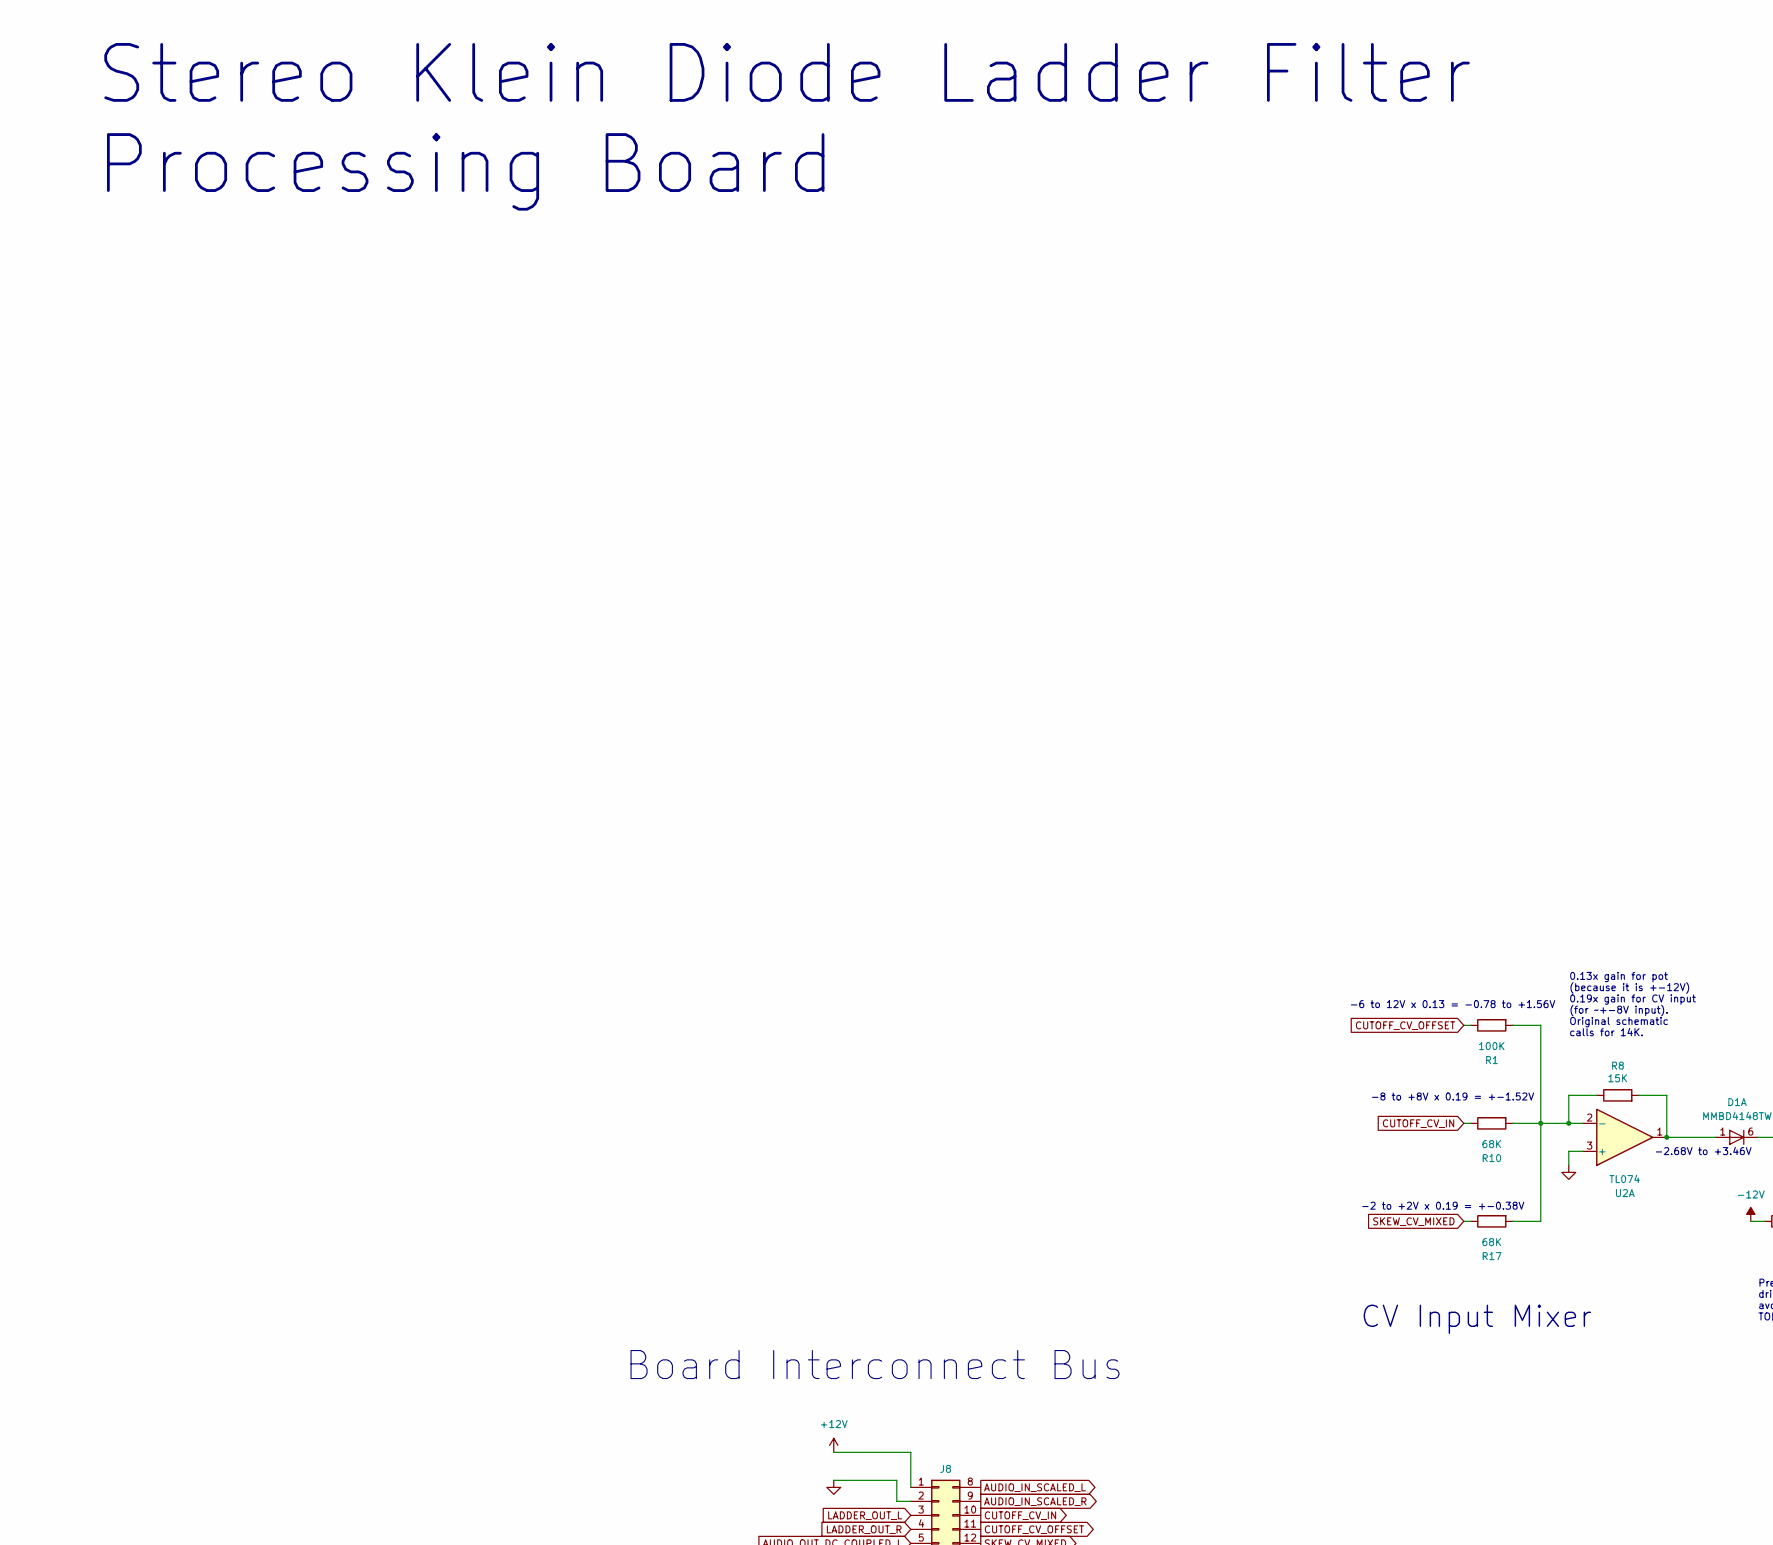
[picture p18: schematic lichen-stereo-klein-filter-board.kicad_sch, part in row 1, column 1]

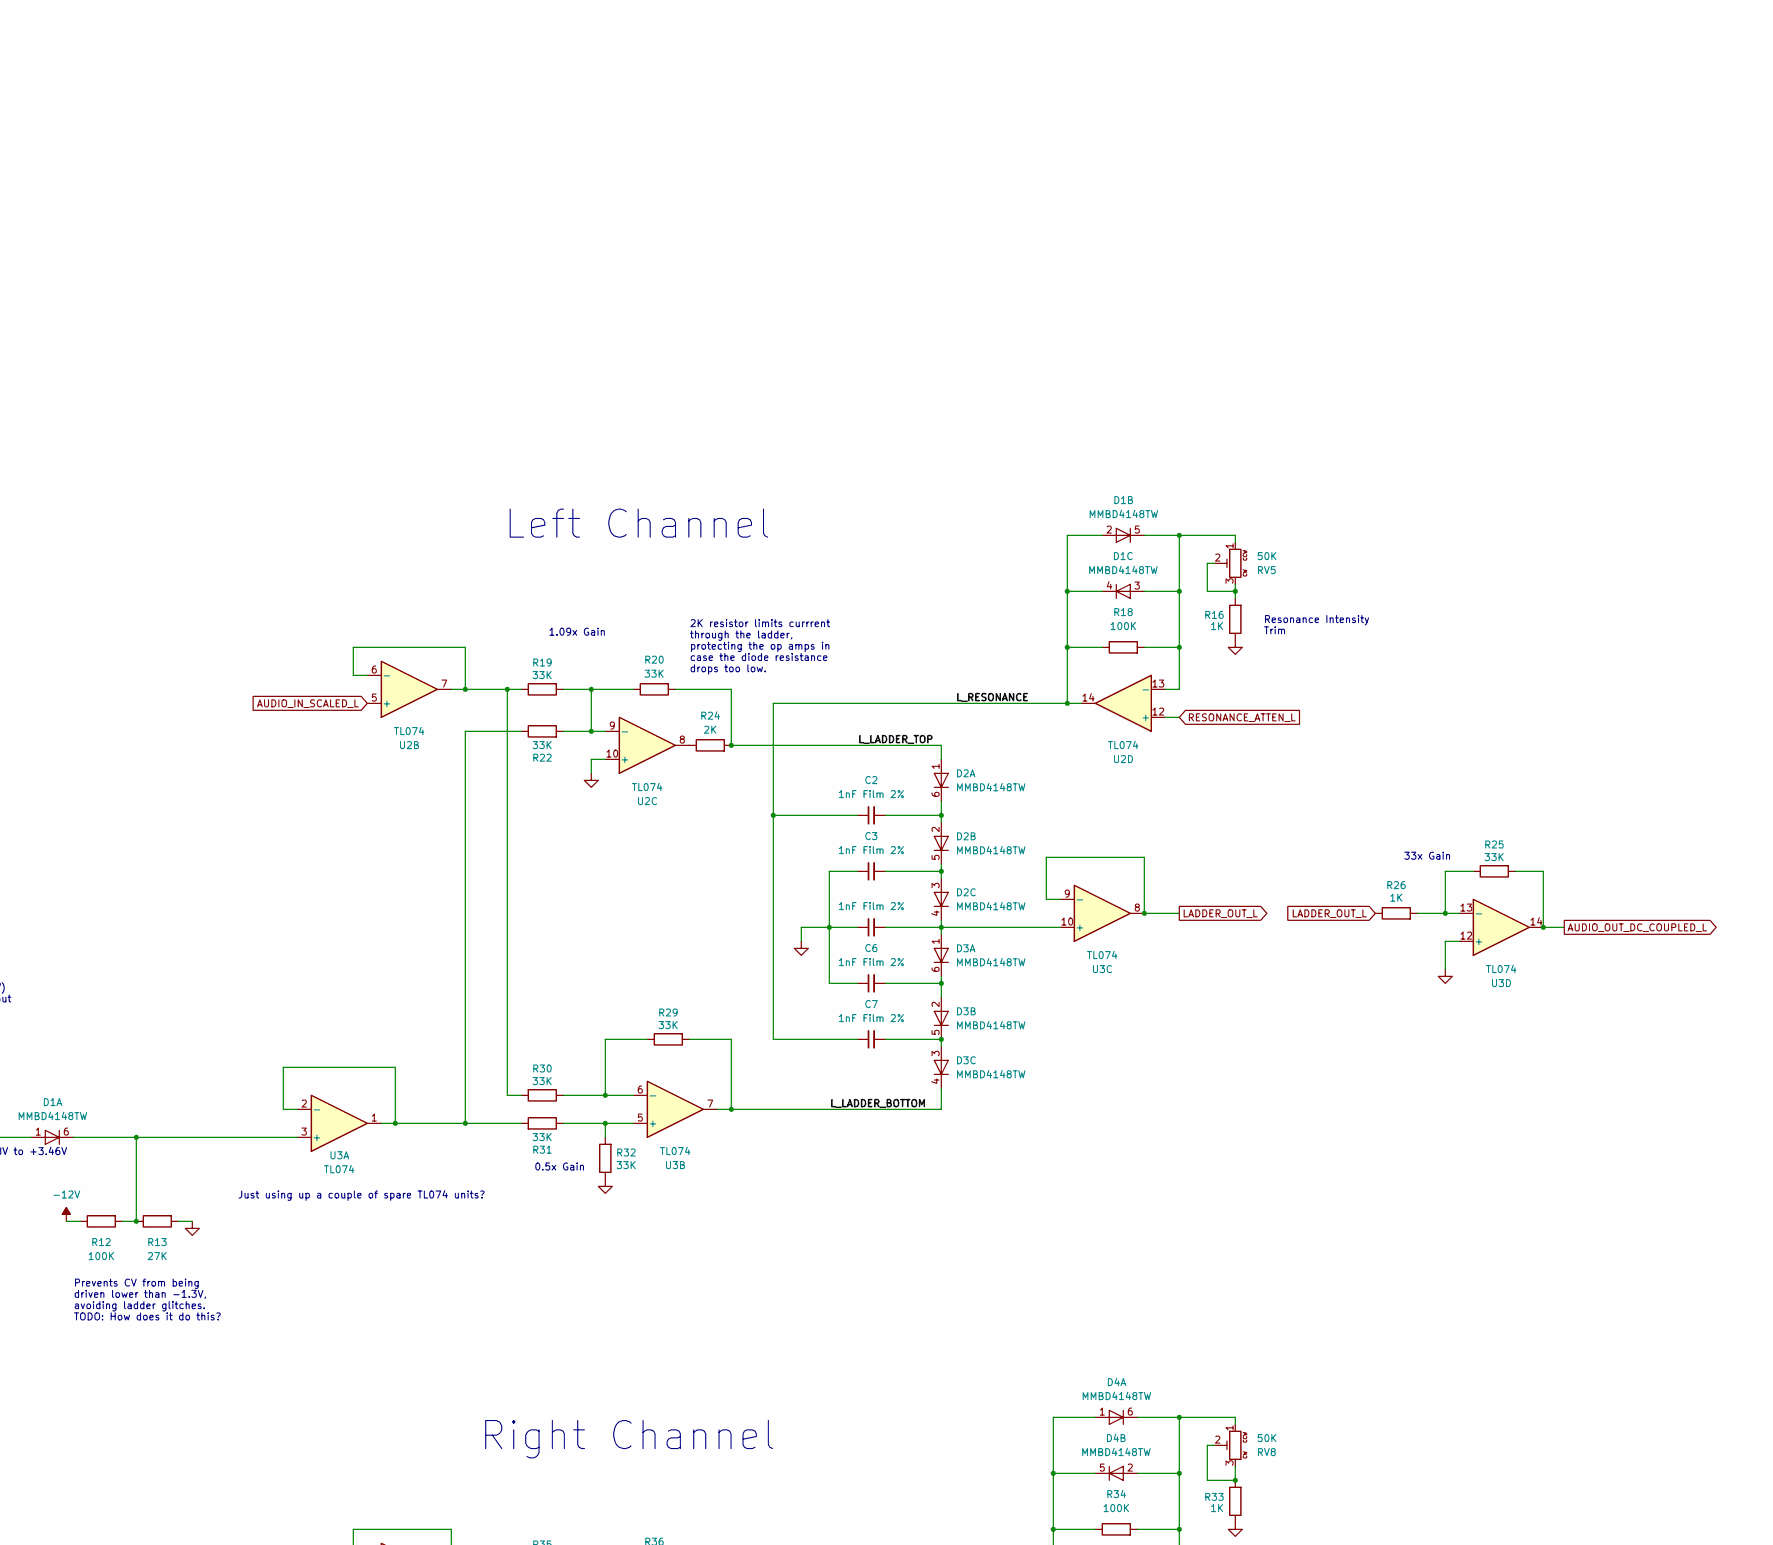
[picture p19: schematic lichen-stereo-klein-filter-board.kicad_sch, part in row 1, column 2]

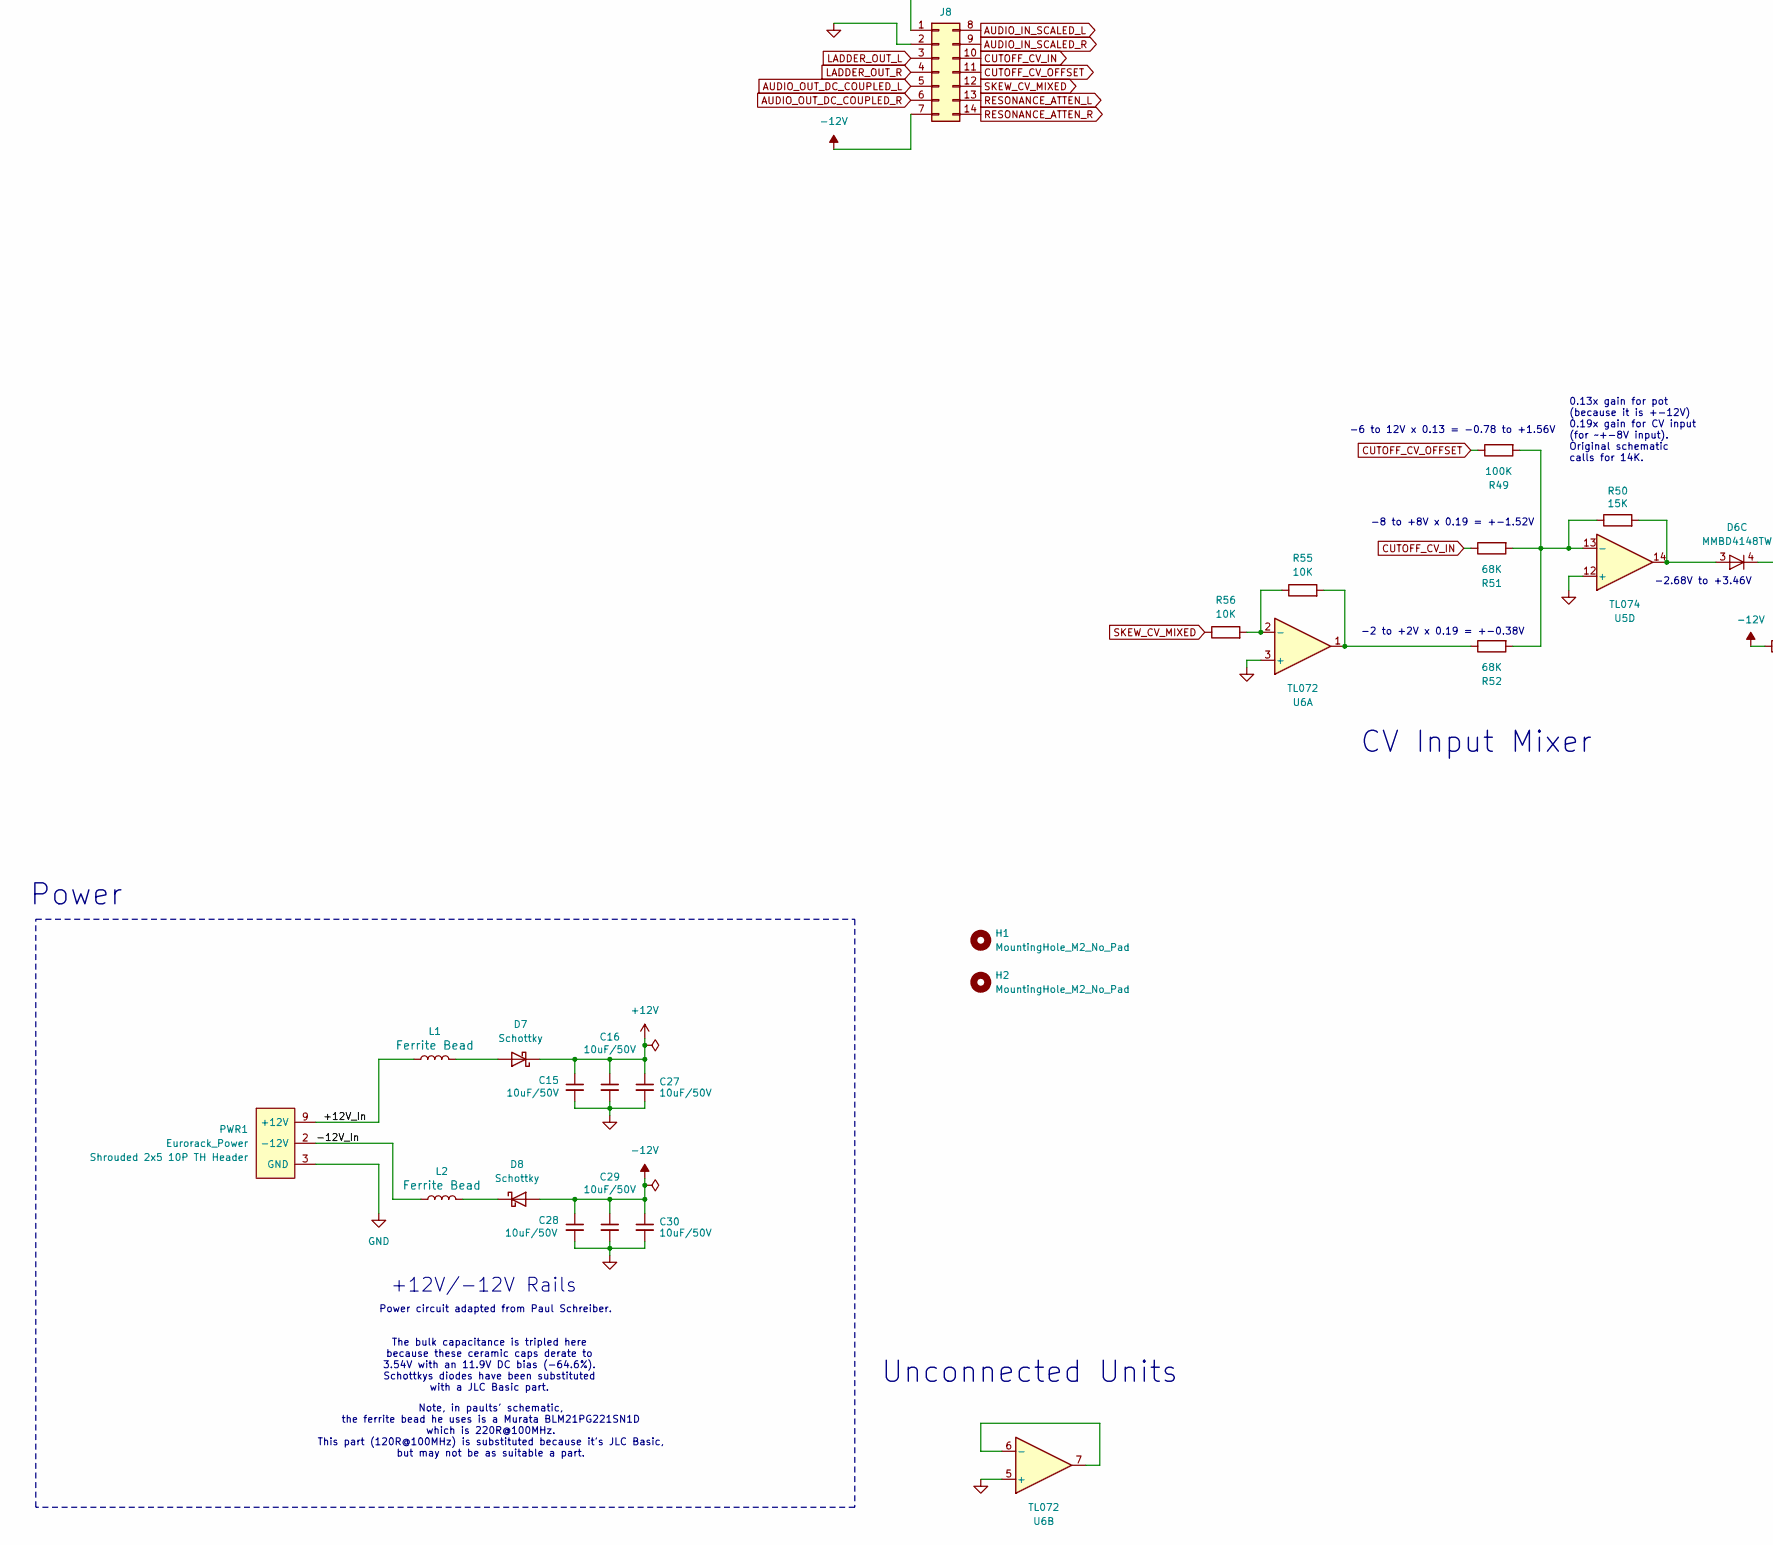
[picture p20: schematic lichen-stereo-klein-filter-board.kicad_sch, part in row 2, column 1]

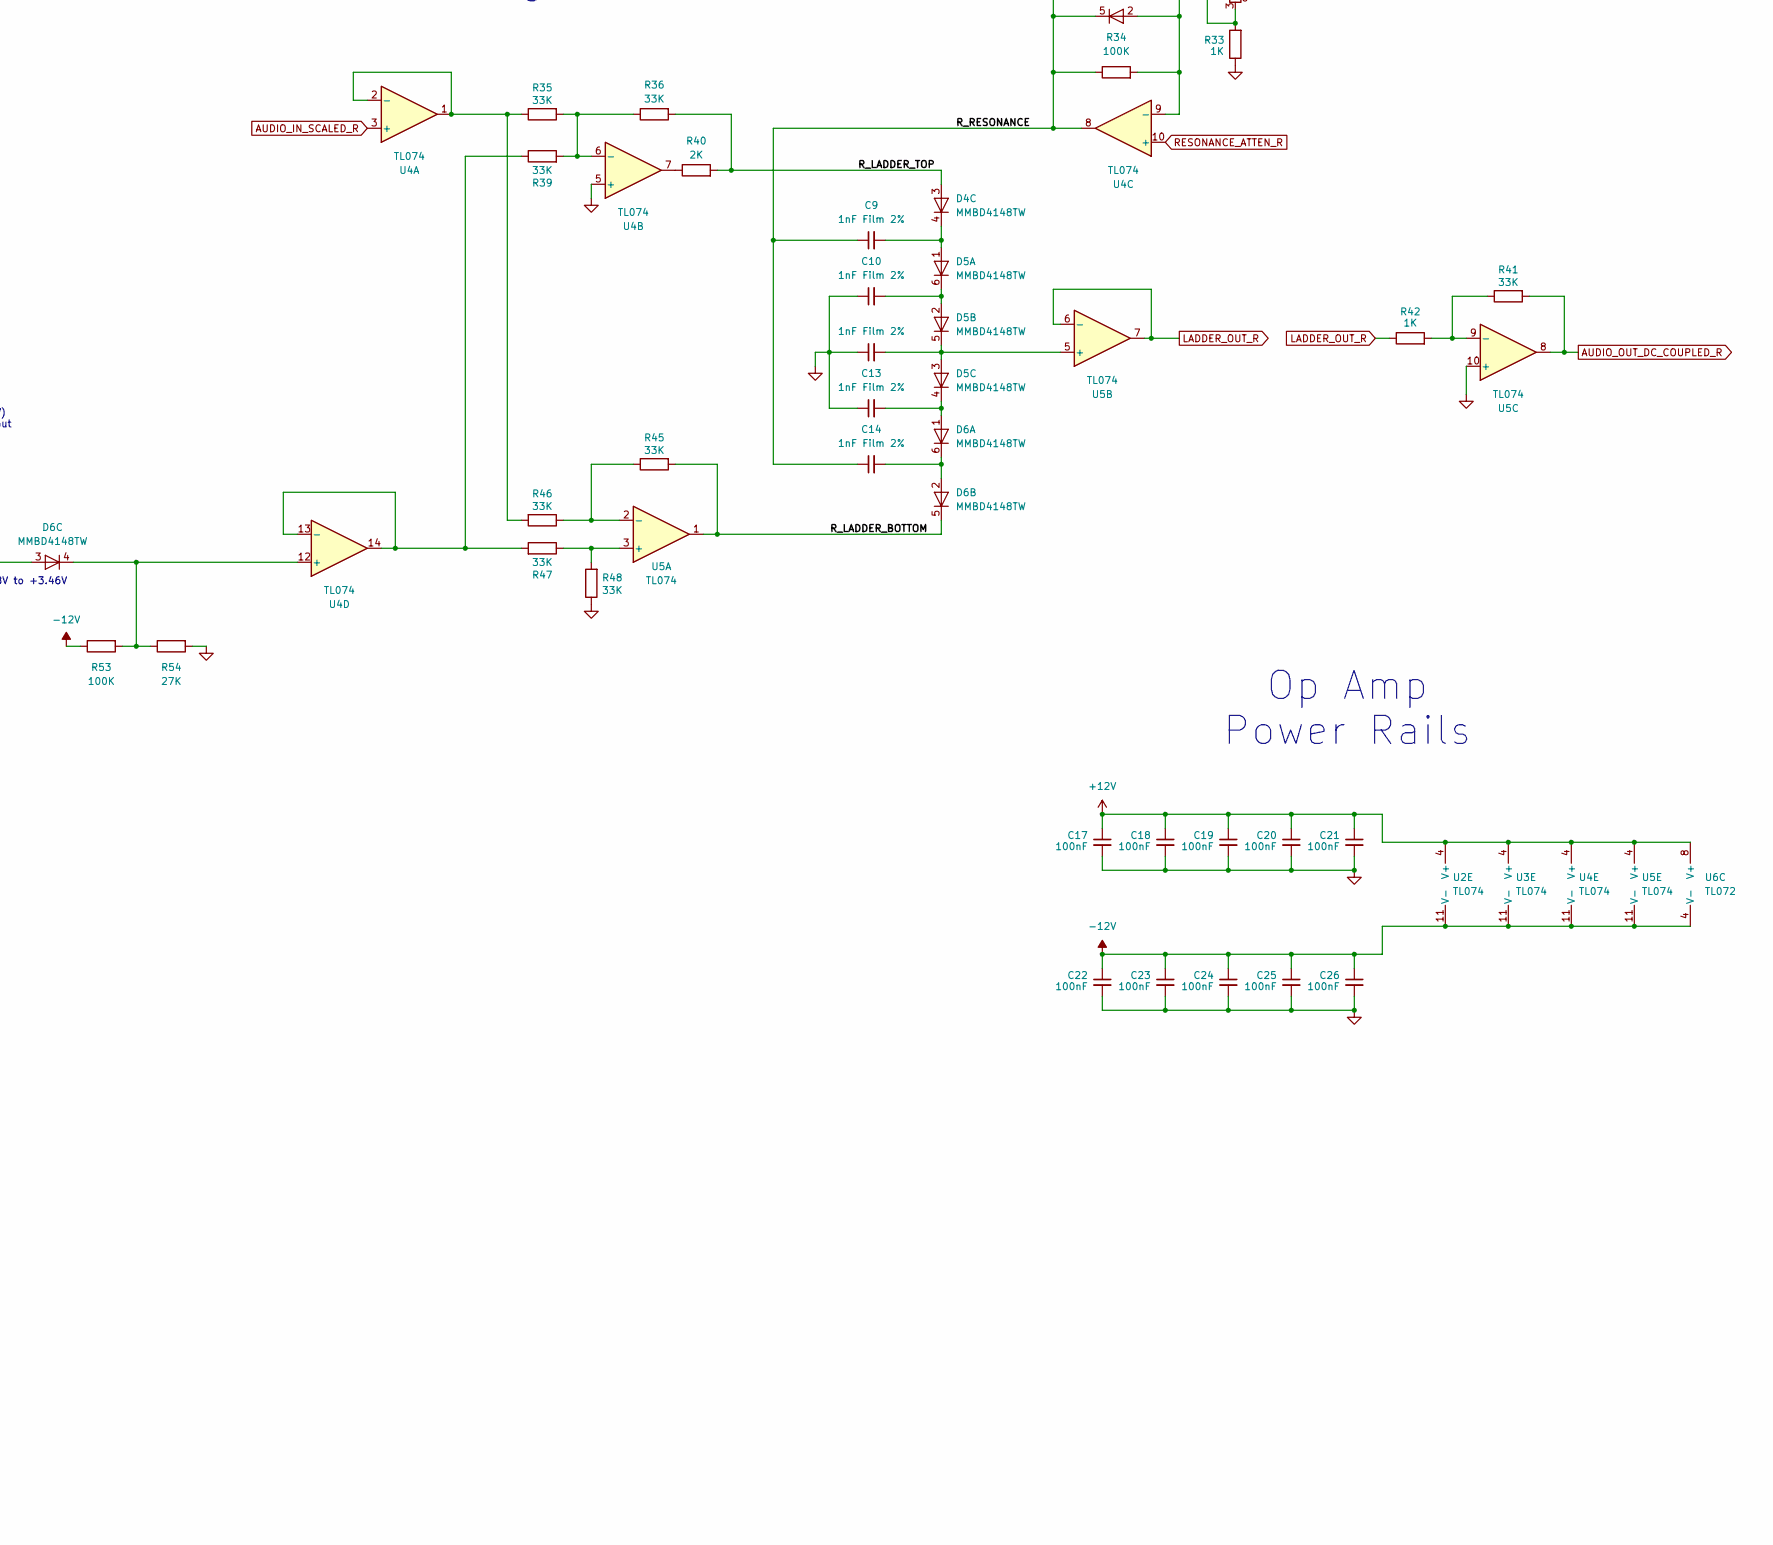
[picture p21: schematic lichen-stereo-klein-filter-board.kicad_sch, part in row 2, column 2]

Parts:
C2, C3, C4, C6, C7, C9, C10, C11, C13, C14: 1nF; C_0805; Part Number ECHU1H102GX5; LCSC C569826
C15, C16, C27, C28, C29, C30: 10uF; C_1206_3216Metric; Part Number CL31A106KBHNNNE; LCSC C13585
C17, C18, C19, C20, C21, C22, C23, C24, C25, C26: 100nF; C_0402_1005Metric_small_pads; Part Number CL05B104KB54PNC; LCSC C307331
D1, D2, D3, D4, D5, D6: MMBD4148TW; SOT-363_SC-70-6; Part Number MMBD4148TW; LCSC C5240652
D7, D8: Schottky; D_SMA_Handsoldering; Part Number SS34; LCSC C8678
H1, H2: MountingHole_M2_No_Pad; MountingHole_2.2mm_M2
J8: 02x07 Pins; PinHeader_2x07_P2.54mm_Vertical_SMD; Part Number 2.54-2*7P针立贴; LCSC C84004
L1, L2: FerriteBead_0603_2A; R_0603; Part Number BLM18PG121SN1D; LCSC C14709
PWR1: Eurorack_Power; Eurorack_Power_Shrouded_TH_Staggered_Small
R1, R12, R18, R34, R49, R53: 100K; R_0603; Part Number 0603WAF1003T5E; LCSC C25803
R8, R50: 15K; R_0603; Part Number 0603WAF1502T5E; LCSC C22809
R10, R17, R51, R52: 68K; R_0603; Part Number 0603WAF6802T5E; LCSC C23231
R13, R54: 27K; R_0603; Part Number 0603WAF2702T5E; LCSC C22967
R16, R26, R33, R42: 1K; R_0603; Part Number 0603WAF1001T5E; LCSC C21190
R19, R20, R22, R25, R29, R30, R31, R32, R35, R36, R39, R41, R45, R46, R47, R48: 33K; R_0603; Part Number 0603WAF3302T5E; LCSC C4216
R24, R40: 2K; R_0603; Part Number 0603WAF2001T5E; LCSC C22975
R55, R56: 10K; R_0603; Part Number 0603WAF1002T5E; LCSC C25804
RV5, RV8: 50K; Potentiometer_Bourns_3266W_Vertical; Part Number 3266W-1-503LF; LCSC C780226
U2, U3, U4, U5: TL074; SOIC-14_3.9x8.7mm_P1.27mm; Part Number TL074IDR; LCSC C6964
U6: TL072; SOIC-8_3.9x4.9mm_P1.27mm; Part Number TL072CDT; LCSC C6961

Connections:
+12V: C15.1, C16.1, C17.1, C18.1, C19.1, C20.1, C21.1, C27.1, D7.1 (K), J8.1, U2.4 (V+), U3.4 (V+), U4.4 (V+), U5.4 (V+), U6.8 (V+)
-12V: C22.1, C23.1, C24.1, C25.1, C26.1, C28.1, C29.1, C30.1, D8.2 (A), J8.7, R12.1, R53.1, U2.11 (V-), U3.11 (V-), U4.11 (V-), U5.11 (V-), U6.4 (V-)
/+12V_In: L1.1, PWR1.9 (+12V), PWR1.10 (+12V)
/-12V_In: L2.1, PWR1.1 (-12V), PWR1.2 (-12V)
/L_LADDER_BOTTOM: D3.4 (K), R29.2, U3.7
/L_LADDER_TOP: D2.1 (A), R20.2, R24.2
/L_RESONANCE: C2.1, C7.1, D1.2 (A), D1.4 (K), R18.1, U2.14
/R_LADDER_BOTTOM: D6.5 (K), R45.2, U5.1
/R_LADDER_TOP: D4.3 (A), R36.2, R40.2
/R_RESONANCE: C9.1, C14.1, D4.1 (A), D4.5 (K), R34.1, U4.8
AUDIO_IN_SCALED_L: J8.8, U2.5 (+)
AUDIO_IN_SCALED_R: J8.9, U4.3 (+)
AUDIO_OUT_DC_COUPLED_L: J8.5, R25.2, U3.14
AUDIO_OUT_DC_COUPLED_R: J8.6, R41.2, U5.8
CUTOFF_CV_IN: J8.10, R10.1, R51.1
CUTOFF_CV_OFFSET: J8.11, R1.1, R49.1
GND: C3.1, C4.1, C6.1, C10.1, C11.1, C13.1, C15.2, C16.2, C17.2, C18.2, C19.2, C20.2, C21.2, C22.2, C23.2, C24.2, C25.2, C26.2, C27.2, C28.2, C29.2, C30.2, J8.2, PWR1.3 (GND), PWR1.4 (GND), PWR1.5 (GND), PWR1.6 (GND), PWR1.7 (GND), PWR1.8 (GND), R13.2, R16.1, R32.1, R33.1, R48.1, R54.2, U2.3 (+), U2.10 (+), U3.12 (+), U4.5 (+), U5.10 (+), U5.12 (+), U6.3 (+), U6.5 (+)
LADDER_OUT_L: J8.3, R26.1, U3.8, U3.9 (-)
LADDER_OUT_R: J8.4, R42.1, U5.6 (-), U5.7
unnamed: D1.1 (A), R8.2, U2.1
unnamed: D1.6 (K), R12.2, R13.1, U3.3 (+)
unnamed: D1.3 (A), D1.5 (K), R18.2, RV5.1, U2.13 (-)
unnamed: C2.2, D2.2 (A), D2.6 (K)
unnamed: C3.2, D2.3 (A), D2.5 (K)
unnamed: C4.2, D2.4 (K), D3.1 (A), U3.10 (+)
unnamed: C6.2, D3.2 (A), D3.6 (K)
unnamed: C7.2, D3.3 (A), D3.5 (K)
unnamed: D4.2 (A), D4.6 (K), R34.2, RV8.1, U4.9 (-)
unnamed: C9.2, D4.4 (K), D5.1 (A)
unnamed: C10.2, D5.2 (A), D5.6 (K)
unnamed: C11.2, D5.3 (A), D5.5 (K), U5.5 (+)
unnamed: C13.2, D5.4 (K), D6.1 (A)
unnamed: C14.2, D6.2 (A), D6.6 (K)
unnamed: D6.3 (A), R50.2, U5.14
unnamed: D6.4 (K), R53.2, R54.1, U4.12 (+)
unnamed: D7.2 (A), L1.2
unnamed: D8.1 (K), L2.2
unnamed: R16.2, RV5.2, RV5.3
unnamed: R24.1, U2.8
unnamed: R33.2, RV8.2, RV8.3
unnamed: R40.1, U4.7
unnamed: R52.1, R55.2, U6.1
unnamed: R1.2, R8.1, R10.2, R17.2, U2.2 (-)
unnamed: R19.1, R30.2, U2.6 (-), U2.7
unnamed: R19.2, R20.1, R22.2, U2.9 (-)
unnamed: R22.1, R31.2, U3.1, U3.2 (-)
unnamed: R31.1, R32.2, U3.5 (+)
unnamed: R29.1, R30.1, U3.6 (-)
unnamed: R25.1, R26.2, U3.13 (-)
unnamed: R35.1, R46.2, U4.1, U4.2 (-)
unnamed: R35.2, R36.1, R39.2, U4.6 (-)
unnamed: R39.1, R47.2, U4.13 (-), U4.14
unnamed: R47.1, R48.2, U5.3 (+)
unnamed: R45.1, R46.1, U5.2 (-)
unnamed: R41.1, R42.2, U5.9 (-)
unnamed: R49.2, R50.1, R51.2, R52.2, U5.13 (-)
unnamed: R55.1, R56.2, U6.2 (-)
unnamed: U6.6 (-), U6.7
RESONANCE_ATTEN_L: J8.13, U2.12 (+)
RESONANCE_ATTEN_R: J8.14, U4.10 (+)
SKEW_CV_MIXED: J8.12, R17.1, R56.1

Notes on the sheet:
-8 to +8V x 0.19 = +-1.52V
-2.68V to +3.46V
CV Input Mixer
Prevents CV from being driven lower than -1.3V, avoiding ladder glitches. TODO: How does it do this?
Board Interconnect Bus
0.13x gain for pot (because it is +-12V) 0.19x gain for CV input (for ~+-8V input). Original schematic calls for 14K.
The bulk capacitance is tripled here because these ceramic caps derate to 3.54V with an 11.9V DC bias (-64.6%). Schottkys diodes have been substituted with a JLC Basic part.
Right Channel
Op Amp Power Rails
Resonance Intensity Trim
0.5x Gain
-2 to +2V x 0.19 = +-0.38V
1.09x Gain
+12V/-12V Rails
-6 to 12V x 0.13 = -0.78 to +1.56V
33x Gain
Unconnected Units
Power
Stereo Klein Diode Ladder Filter Processing Board
Left Channel
Just using up a couple of spare TL074 units?
Note, in paults' schematic, the ferrite bead he uses is a Murata BLM21PG221SN1D which is 220R@100MHz. This part (120R@100MHz) is substituted because it's JLC Basic, but may not be as suitable a part.
Power circuit adapted from Paul Schreiber.
2K resistor limits currrent through the ladder, protecting the op amps in case the diode resistance drops too low.



Board: 4 copper layers, 29.0 x 108.0 mm, 85 parts (5 on the bottom side), 61 nets.

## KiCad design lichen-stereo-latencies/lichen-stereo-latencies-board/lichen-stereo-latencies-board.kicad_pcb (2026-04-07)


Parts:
H1, H2: MountingHole_M2_No_Pad; MountingHole_2.2mm_M2
J1: 02x05 Socket; PinSocket_2x05_P2.54mm_Vertical
J2: 2x5 Socket; PinSocket_2x05_P2.54mm_Vertical

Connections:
CV1_INPUT: J1.1; also elsewhere on the board
CV2_INPUT: J2.1; also elsewhere on the board
CV_L1_ATTEN: J1.2; also elsewhere on the board
CV_L1_BUFFERED: J1.6; also elsewhere on the board
CV_L2_ATTEN: J2.2; also elsewhere on the board
CV_L2_BUFFERED: J2.6; also elsewhere on the board
CV_NORM_5.5V: J1.10; also elsewhere on the board
CV_R1_ATTEN: J1.3; also elsewhere on the board
CV_R1_BUFFERED: J1.7; also elsewhere on the board
CV_R2_ATTEN: J2.3; also elsewhere on the board
CV_R2_BUFFERED: J2.7; also elsewhere on the board
GND: J2.9; also elsewhere on the board
L1_INPUT: J1.4; also elsewhere on the board
L2_INPUT: J2.4; also elsewhere on the board
L_OUTPUT: J1.8; also elsewhere on the board
R1_INPUT: J1.5; also elsewhere on the board
R2_INPUT: J2.5; also elsewhere on the board
R_OUTPUT: J1.9; also elsewhere on the board


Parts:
C7, C8: 10uF; C_0805; Part Number GRM21BR61H106KE43L; LCSC C440198
D1, D2: Schottky; D_SMA_Handsoldering; Part Number SS34; LCSC C8678
L1, L2: FerriteBead_0603_2A; R_0603; Part Number BLM18PG121SN1D; LCSC C14709
PWR1: Eurorack_Power; Eurorack_Power_Shrouded_TH_Staggered_Small
R21: 10K; R_0402_1005Metric; Part Number 0402WGF1002TCE; LCSC C25744
R22: 12K; R_0402_1005Metric; Part Number 0402WGF1202TCE; LCSC C25752
U1, U3, U5, U7: TL074; SOIC-14_3.9x8.7mm_P1.27mm; Part Number TL074IDR; LCSC C6964

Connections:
+12V: C8.1, D1.1 (K), R22.1, U1.4 (V+), U3.4 (V+), U5.4 (V+), U7.11 (V-)
-12V: C7.1, D2.2 (A), U1.11 (V-), U3.11 (V-), U5.11 (V-), U7.4 (V+)
/Power/+12V_In: L1.1, PWR1.9 (+12V), PWR1.10 (+12V)
/Power/-12V_In: L2.1, PWR1.1 (-12V), PWR1.2 (-12V)
CV_NORM_5.5V: R21.1, R22.2; also elsewhere on the board
GND: C7.2, C8.2, PWR1.3 (GND), PWR1.4 (GND), PWR1.5 (GND), PWR1.6 (GND), PWR1.7 (GND), PWR1.8 (GND), R21.2; also elsewhere on the board
unnamed: D1.2 (A), L1.2
unnamed: D2.1 (K), L2.2

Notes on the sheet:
12V × 10K/(12K+10K) = 5.45V 12K || 10K = 5.45K 5.45V / 5450Ω = 1 mA
Power circuit from Paul Schreiber.
Note, in paults' schematic, the ferrite bead he uses is a Murata BLM21PG221SN1D which is 220R@100MHz. This part (120R@100MHz) is substituted because it's JLC Basic, but may not be as suitable a part. He also specifies STM STPS1L30U for the Schottky diode, which has been substituted here for a JLC b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
+12V/-12V Rails


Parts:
C5, C6: 33pF C0G; C_0603; Part Number CL10C330JB8NNNC; LCSC C1663
R13, R14, R16, R17, R18, R20: 100K; R_0402_1005Metric; Part Number 0402WGF1003TCE; LCSC C25741
R15, R19: 1K; R_0402_1005Metric; Part Number 0402WGF1001TCE; LCSC C11702
U3, U7: TL074; SOIC-14_3.9x8.7mm_P1.27mm; Part Number TL074IDR; LCSC C6964

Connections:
/Channel 1/L1_OUTPUT: R14.1; also elsewhere on the board
/Channel 2/L2_OUTPUT: R16.1; also elsewhere on the board
/Channel 2/R2_OUTPUT: R20.1; also elsewhere on the board
/Mixer/L_MIXED: C5.2, R13.1, R14.2, R16.2, U3.13 (-)
/Mixer/R_MIXED: C6.2, R17.1, R18.2, R20.2, U7.13 (-)
GND: U3.12 (+), U7.12 (+); also elsewhere on the board
L_OUTPUT: C5.1, R13.2, R15.2; also elsewhere on the board
unnamed: R15.1, U3.14
unnamed: R19.1, U7.14
R1_OUTPUT: R18.1; also elsewhere on the board
R_OUTPUT: C6.1, R17.2, R19.2; also elsewhere on the board

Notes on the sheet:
Unity gain buffer, 1k output inpedance. Op amp feedback filter 48.2KHz cutoff

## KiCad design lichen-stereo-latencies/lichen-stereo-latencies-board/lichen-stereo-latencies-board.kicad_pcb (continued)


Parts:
C1, C2: 0.1uF film; C_Rect_L7.2mm_W2.5mm_P5.00mm_FKS2_FKP2_MKS2_MKP2
R1, R2, R3, R4, R5, R6: 100K; R_0402_1005Metric; Part Number 0402WGF1003TCE; LCSC C25741
U1, U3: TL074; SOIC-14_3.9x8.7mm_P1.27mm; Part Number TL074IDR; LCSC C6964
U2, U4: NSL-32R3 60R@20mA; NSL-32; Part Number NSL-32SR3

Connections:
/Channel 1/CV1_BUFFERED: R1.2, U1.1, U1.5 (+), U1.10 (+)
/Channel 1/L1_BUFFERED: R3.2, U2.3 (R), U3.1
/Channel 1/L1_OUTPUT: U1.13 (-), U1.14; also elsewhere on the board
/Channel 1/L1_VACTROL_OUTPUT: C1.1, U1.12 (+), U2.4 (R)
/Channel 1/R1_BUFFERED: R5.2, U3.7, U4.3 (R)
/Channel 1/R1_VACTROL_OUTPUT: C2.1, U3.10 (+), U4.4 (R)
CV1_INPUT: R2.1; also elsewhere on the board
CV_L1_ATTEN: U2.2 (K); also elsewhere on the board
CV_L1_BUFFERED: U1.6 (-), U1.7; also elsewhere on the board
CV_R1_ATTEN: U4.2 (K); also elsewhere on the board
CV_R1_BUFFERED: U1.8, U1.9 (-); also elsewhere on the board
GND: C1.2, C2.2, U1.3 (+), U2.1 (A), U3.3 (+), U3.5 (+), U4.1 (A); also elsewhere on the board
L1_INPUT: R4.1; also elsewhere on the board
unnamed: R1.1, R2.2, U1.2 (-)
unnamed: R3.1, R4.2, U3.2 (-)
unnamed: R5.1, R6.2, U3.6 (-)
R1_INPUT: R6.1; also elsewhere on the board
R1_OUTPUT: U3.8, U3.9 (-); also elsewhere on the board

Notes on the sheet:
Unity gain buffer, 100k input impedance.
Unity gain buffer, 1k output inpedance. Op amp feedback filter 48.2KHz cutoff
NSL-32SR3 resistance @ 20mA is 60R max cutoff frequency is: 0.1uF = 26.5KHz @ 20mA, 10.6KHz @ 5mA 0.15uF = 16.7KHz @ 20mA, 7.1KHz @ 5mA 0.22uF = 12.1Hz @ 20mA, 4.8KHz @ 5mA 0.47uF = 5.6KHz @ 20mA, 2.3KHz @ 5mA
Vactrol LED connection is backwards, because the CV has been inverted.


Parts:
C3, C4: 0.1uF film; C_Rect_L7.2mm_W2.5mm_P5.00mm_FKS2_FKP2_MKS2_MKP2
R7, R8, R9, R10, R11, R12: 100K; R_0402_1005Metric; Part Number 0402WGF1003TCE; LCSC C25741
U5, U7: TL074; SOIC-14_3.9x8.7mm_P1.27mm; Part Number TL074IDR; LCSC C6964
U6, U8: NSL-32R3 60R@20mA; NSL-32; Part Number NSL-32SR3

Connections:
/Channel 2/CV2_BUFFERED: R7.2, U5.1, U5.5 (+), U5.10 (+)
/Channel 2/L2_OUTPUT: U5.13 (-), U5.14; also elsewhere on the board
/Channel 2/L2_VACTROL_OUTPUT: C3.1, U5.12 (+), U6.4 (R)
/Channel 2/R2_OUTPUT: U7.8, U7.9 (-); also elsewhere on the board
/Channel 2/R2_VACTROL_OUTPUT: C4.1, U7.10 (+), U8.4 (R)
CV2_INPUT: R8.1; also elsewhere on the board
CV_L2_ATTEN: U6.2 (K); also elsewhere on the board
CV_L2_BUFFERED: U5.6 (-), U5.7; also elsewhere on the board
CV_R2_ATTEN: U8.2 (K); also elsewhere on the board
CV_R2_BUFFERED: U5.8, U5.9 (-); also elsewhere on the board
GND: C3.2, C4.2, U5.3 (+), U6.1 (A), U7.3 (+), U7.5 (+), U8.1 (A); also elsewhere on the board
L2_INPUT: R10.1; also elsewhere on the board
unnamed: R9.2, U6.3 (R), U7.1
unnamed: R11.2, U7.7, U8.3 (R)
unnamed: R7.1, R8.2, U5.2 (-)
unnamed: R9.1, R10.2, U7.2 (-)
unnamed: R11.1, R12.2, U7.6 (-)
R2_INPUT: R12.1; also elsewhere on the board

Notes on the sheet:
NSL-32SR3 resistance @ 20mA is 60R max cutoff frequency is: 0.1uF = 26.5KHz @ 20mA, 10.6KHz @ 5mA 0.15uF = 16.7KHz @ 20mA, 7.1KHz @ 5mA 0.22uF = 12.1Hz @ 20mA, 4.8KHz @ 5mA 0.47uF = 5.6KHz @ 20mA, 2.3KHz @ 5mA
Unity gain buffer, 1k output inpedance. Op amp feedback filter 48.2KHz cutoff
Unity gain buffer, 100k input impedance.
Vactrol LED connection is backwards, because the CV has been inverted.



Board: 2 copper layers, 19.0 x 108.0 mm, 47 parts (9 on the bottom side), 48 nets.

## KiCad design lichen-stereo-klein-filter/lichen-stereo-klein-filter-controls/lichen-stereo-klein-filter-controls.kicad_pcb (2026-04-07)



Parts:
C1, C5, C8, C12: 1uF film; C_Rect_L7.2mm_W2.5mm_P5.00mm_FKS2_FKP2_MKS2_MKP2
C31, C32: 100nF; C_0402_1005Metric_small_pads; Part Number CL05B104KB54PNC; LCSC C307331
H1, H2: MountingHole_M2_No_Pad; MountingHole_2.2mm_M2
J1, J2: Thonkiconn_Mono_Audio_Jack; Audio_Jack_Thonkiconn_Mono; Part Number WQP518MA/PJ398SM
J3, J6: Thonkiconn_Mono_Audio_Jack; Audio_Jack_Thonkiconn_Mono_Right_Overhang; Part Number WQP518MA/PJ398SM
J4, J5: Thonkiconn_Mono_Audio_Jack; Audio_Jack_Thonkiconn_Mono_Left_Overhang; Part Number WQP518MA/PJ398SM
J7: 02x07 Socket; PinSocket_2x07_P2.54mm_Vertical_SMD; Part Number 2.54-2*7PFemale Headers; LCSC C84005
R2: 27K; R_0603; Part Number 0603WAF2702T5E; LCSC C22967
R3, R6, R9, R15: 10K; R_0603; Part Number 0603WAF1002T5E; LCSC C25804
R4, R5: 10K; R_0603; Part Number 0603WAF1002T5E; JLCPCB ID C25804
R7, R27, R43: 1K; R_0603; Part Number 0603WAF1001T5E; LCSC C21190
R11: 12K; R_0603; Part Number 0603WAF1202T5E; LCSC C22790
R14, R21, R28, R37, R44: 100K; R_0603; Part Number 0603WAF1003T5E; LCSC C25803
R23, R38: 2K; R_0603; Part Number 0603WAF2001T5E; LCSC C22975
RV1, RV2, RV3, RV4: B100K; Potentiometer_Alpha_RD901_Eurorack; Part Number RD901F-40
RV7: B100K; Potentiometer_Alpha_RD902F-40-00D_Dual_Vertical; Part Number RD90F-40
U1: TL074; SOIC-14_3.9x8.7mm_P1.27mm; Part Number TL074IDR; LCSC C6964

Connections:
+12V: C31.1, J7.1, R4.2, RV1.3, U1.4 (V+)
-12V: C32.1, J7.7, R2.2, U1.11 (V-)
/1V1: R4.1, R7.1, U1.3 (+)
/1V1_BUFFERED: R6.1, RV2.3, U1.1, U1.2 (-)
/1V1_INV: R3.2, RV2.1, U1.8
/AUDIO_OUT_FILTERED_L: C5.2, R27.1, R28.2
/AUDIO_OUT_FILTERED_R: C12.2, R43.1, R44.2
/CV_IN: J1.T, RV3.3
/IN_L: C1.1, J4.T, J5.TN
/IN_R: C8.1, J5.T
/SKEW_CV: J2.T, RV4.3
/SKEW_CV_ATTEN: R14.1, RV4.2
/SKEW_CV_SCALED: R11.2, R15.1, U1.7
AUDIO_IN_SCALED_L: J7.8, R21.2, R23.1
AUDIO_IN_SCALED_R: J7.9, R37.2, R38.1
AUDIO_OUT_DC_COUPLED_L: C5.1, J7.5
AUDIO_OUT_DC_COUPLED_R: C12.1, J7.6
CUTOFF_CV_IN: J7.10, RV3.2
CUTOFF_CV_OFFSET: J7.11, RV1.2
GND: C31.2, C32.2, J1.S, J2.S, J3.S, J4.S, J5.S, J6.S, J7.2, R7.2, R23.2, R28.1, R38.2, R44.1, RV3.1, RV4.1, RV7.1, RV7.4, U1.5 (+), U1.10 (+), U1.12 (+)
LADDER_OUT_L: J7.3, RV7.6
LADDER_OUT_R: J7.4, RV7.3
unnamed: C1.2, R21.1
unnamed: C8.2, R37.1
unnamed: J3.T, R27.2
unnamed: J6.T, R43.2
unnamed: R2.1, RV1.1
unnamed: R5.1, RV2.2
unnamed: R11.1, R14.2, U1.6 (-)
unnamed: R3.1, R6.2, U1.9 (-)
unnamed: R5.2, R9.1, R15.2, U1.13 (-)
RESONANCE_ATTEN_L: J7.13, RV7.5
RESONANCE_ATTEN_R: J7.14, RV7.2
SKEW_CV_MIXED: J7.12, R9.2, U1.14

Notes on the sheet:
Filter Outputs
HPF cutoff: 1.6 Hz
Resonance
Cutoff Skew CV
I/O
Scales input to ~196mV
Left Audio Input
Cutoff CV
-1V1
+1V1
Filter Inputs
0.12x gain
Right Audio Input
Board Interconnect Bus
1.09V
27K raises minimum voltage to -6V, setting a default cutoff frequency.



Board: 2 copper layers, 29.0 x 108.0 mm, 39 parts (22 on the bottom side), 34 nets.

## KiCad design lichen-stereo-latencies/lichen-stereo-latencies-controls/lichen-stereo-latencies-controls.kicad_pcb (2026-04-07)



Board: 2 copper layers, 19.0 x 108.0 mm, 14 parts (2 on the bottom side), 20 nets.

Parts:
H1, H2: MountingHole_M2_No_Pad; MountingHole_2.2mm_M2
J1: 02x05 Pins; PinHeader_2x05_P2.54mm_Vertical
J2: 2x5 Pins; PinHeader_2x05_P2.54mm_Vertical
J3, J4, J7, J9: Thonkiconn_Mono_Audio_Jack; Audio_Jack_Thonkiconn_Mono_Left_Overhang
J5, J6, J8, J10: Thonkiconn_Mono_Audio_Jack; Audio_Jack_Thonkiconn_Mono_Right_Overhang
RV1, RV2: B10K; Potentiometer_Alpha_RD902F-40-00D_Dual_Vertical

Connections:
CV1_INPUT: J1.1, J3.T, J6.TN
CV2_INPUT: J2.1, J6.T
CV_L1_ATTEN: J1.2, RV1.5
CV_L1_BUFFERED: J1.6, RV1.6
CV_L2_ATTEN: J2.2, RV2.5
CV_L2_BUFFERED: J2.6, RV2.6
CV_NORM_5V: J1.10, J3.TN
CV_R1_ATTEN: J1.3, RV1.2
CV_R1_BUFFERED: J1.7, RV1.3
CV_R2_ATTEN: J2.3, RV2.2
CV_R2_BUFFERED: J2.7, RV2.3
GND: J2.10, J3.S, J4.S, J5.S, J6.S, J7.S, J8.S, J9.S, J10.S, RV1.1, RV1.4, RV2.1, RV2.4
L1_INPUT: J1.4, J4.T
L1_OUTPUT: J5.TN, J7.TN
L2_INPUT: J2.4, J7.T
L_OUTPUT: J1.8, J9.T
R1_INPUT: J1.5, J5.T
R1_OUTPUT: J2.8, J8.TN
R2_INPUT: J2.5, J8.T
R_OUTPUT: J1.9, J10.T

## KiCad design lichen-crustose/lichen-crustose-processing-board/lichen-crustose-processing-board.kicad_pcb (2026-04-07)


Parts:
CONN1: 1x10_Socket; PinSocket_1x10_P2.54mm_Vertical
H1, H2, H3: MountingHole_Pad; MountingHole_2.2mm_M2_Pad

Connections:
+12V: CONN1.1; also elsewhere on the board
-2.5V: CONN1.5; also elsewhere on the board
-12V: CONN1.6; also elsewhere on the board
/CARRER_L_SOCKET: CONN1.8; also elsewhere on the board
/CARRIER_R_SOCKET: CONN1.10; also elsewhere on the board
/PROGRAM_L_SOCKET: CONN1.7; also elsewhere on the board
/PROGRAM_R_SOCKET: CONN1.9; also elsewhere on the board
/RM_L_SOCKET: CONN1.4; also elsewhere on the board
/RM_R_SOCKET: CONN1.3; also elsewhere on the board
GND: CONN1.2, H1.1, H2.1, H3.1; also elsewhere on the board


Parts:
C1, C2, C4, C5, C6, C7: 10uF; C_0805; Part Number GRM21BR61H106KE43L; LCSC C440198
D1, D2: Schottky; D_SMA_Handsoldering; Part Number SS34; LCSC C8678
L1, L2: FerriteBead_0603_2A; R_0603; Part Number BLM18PG121SN1D; LCSC C14709
PWR1: Eurorack_Power; Eurorack_Power_Shrouded_TH_Staggered
R1: 39K; R_0603; Part Number 0603WAF3902T5E; LCSC C23153
R2: 10K; R_0603; Part Number 0603WAF1002T5E; LCSC C25804

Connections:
+12V: C2.1, C4.1, C5.1, D1.1 (K); also elsewhere on the board
-2.5V: R1.2, R2.1; also elsewhere on the board
-12V: C1.1, C6.1, C7.1, D2.2 (A), R1.1; also elsewhere on the board
/Power/+12V_In: L1.1, PWR1.9 (+12V), PWR1.10 (+12V)
/Power/-12V_In: L2.1, PWR1.1 (-12V), PWR1.2 (-12V)
GND: C1.2, C2.2, C4.2, C5.2, C6.2, C7.2, PWR1.3 (GND), PWR1.4 (GND), PWR1.5 (GND), PWR1.6 (GND), PWR1.7 (GND), PWR1.8 (GND), R2.2; also elsewhere on the board
unnamed: D1.2 (A), L1.2
unnamed: D2.1 (K), L2.2

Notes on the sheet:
Note, in paults' schematic, the ferrite bead he uses is a Murata BLM21PG221SN1D which is 220R@100MHz. This part (120R@100MHz) is substituted because it's JLC Basic, but may not be as suitable a part.
(-12V*10KΩ)/(39KΩ+10KΩ) = -2.45V
Power circuit from Paul Schreiber.
+12V/-12V Rails


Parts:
LED1, LED2, LED3, LED4, LED5, LED6, LED7, LED8: White; LED_D3.0mm_Polarity_Indicated
TR1, TR2, TR3, TR4: Transformer_42TM018; 42TM018

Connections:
/CARRER_L_SOCKET: TR1.5; also elsewhere on the board
/CARRIER_R_SOCKET: TR2.5; also elsewhere on the board
/PROGRAM_L_SOCKET: TR1.1; also elsewhere on the board
/PROGRAM_R_SOCKET: TR2.1; also elsewhere on the board
/RM_L_SOCKET: TR4.1; also elsewhere on the board
/RM_R_SOCKET: TR3.1; also elsewhere on the board
GND: TR1.3, TR2.3, TR3.3, TR3.5, TR4.3, TR4.5; also elsewhere on the board
unnamed: LED1.2 (A), LED4.1 (K), TR3.4
unnamed: LED1.1 (K), LED3.2 (A), TR1.6
unnamed: LED2.2 (A), LED6.1 (K), TR4.4
unnamed: LED2.1 (K), LED5.2 (A), TR2.6
unnamed: LED3.1 (K), LED7.2 (A), TR3.6
unnamed: LED4.2 (A), LED7.1 (K), TR1.4
unnamed: LED5.1 (K), LED8.2 (A), TR4.6
unnamed: LED6.2 (A), LED8.1 (K), TR2.4



Board: 2 copper layers, 48.0 x 108.0 mm, 29 parts (13 on the bottom side), 22 nets.

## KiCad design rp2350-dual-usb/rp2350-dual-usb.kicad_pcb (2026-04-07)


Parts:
C1, C6, C11, C12, C13, C14, C15, C16, C17, C18, C19: 100nF; C_0402_1005Metric_small_pads; Part Number CL05B104KB54PNC; LCSC C307331
C2: 1uF; C_0805; Part Number CL21B105KBFNNNE; LCSC C28323
C3, C7, C9, C10: 4.7uF; C_0402_1005Metric_small_pads; Part Number CL05A475MP5NRNC; LCSC C23733
C4, C5: 15pF; C_0402_1005Metric_small_pads; Part Number 0402CG150J500NT; LCSC C1548
C8: 4.7uF; C_0805; Part Number CL21A475KAQNNNE; LCSC C1779
D1: Yellow; LED_0805_2012Metric_Pad1.15x1.40mm_HandSolder; Part Number KT-0805Y; LCSC C2296
D2: Green; LED_0805_2012Metric_Pad1.15x1.40mm_HandSolder; Part Number KT-0805G; LCSC C2297
H1, H2: MountingHole; MountingHole_2.2mm_M2
J1: Conn_01x03_MountingPin; JST_SH_SM03B-SRSS-TB_1x03-1MP_P1.00mm_Horizontal; Part Number SM03B-SRSS-TB; LCSC C160403
L1: 3.3uH; L_pol_2016; Part Number AOTA-B201610S3R3-101-T; LCSC C42411119
R1: 33R; R_0402_1005Metric; Part Number 0402WGF330JTCE; LCSC C25105
R2: 1k; R_0402_1005Metric; Part Number 0402WGF1001TCE; LCSC C11702
R3, R4, R17, R18: 27R; R_0402_1005Metric; Part Number 0402WGF270JTCE; LCSC C25100
R5, R16: 1K; R_0402_1005Metric; Part Number 0402WGF1001TCE; LCSC C11702
R6: 1.5K; R_0402_1005Metric; Part Number 0402WGF1501TCE; LCSC C25867
SW1: 1P1T Switch; SW_SPST_TS-1088-xR020; Part Number TS-1088-AR02016; LCSC C720477
U1: LDL1117-3.3; SOT-223-3_TabPin2; Part Number LDL1117S33R; LCSC C435835
U2: RP2354_60QFN; RP2350-QFN-60-1EP_7x7_P0.4mm_EP3.4x3.4mm_ThermalVias; Part Number RP2354A; LCSC C41378174
Y1: 12MHz; Crystal_SMD_3225-4Pin_3.2x2.5mm; Part Number ABM8-272-T3; LCSC C20625731

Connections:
+1V1: C1.1, C3.1, C6.1, C9.1, L1.1, U2.6 (DVDD), U2.23 (DVDD), U2.39 (DVDD), U2.50 (VREG_FB)
+3V3: C7.1, C8.1, C11.1, C12.1, C13.1, C14.1, C15.1, C16.1, C17.1, C18.1, C19.1, R1.1, U1.2 (VO), U2.1 (IOVDD), U2.11 (IOVDD), U2.20 (IOVDD), U2.30 (IOVDD), U2.38 (IOVDD), U2.44 (ADC_AVDD), U2.45 (IOVDD), U2.49 (VREG_VIN), U2.53 (USB_OTP_VDD), U2.54 (QSPI_IOVDD); also elsewhere on the board
/CRYSTAL_IN: C4.2, U2.21 (XIN), Y1.1
/CRYSTAL_OUT: C5.2, R16.2, Y1.3
/GPIO24_LED_GREEN: R6.2, U2.36 (GPIO24)
/GPIO25_LED_YELLOW: R5.2, U2.37 (GPIO25)
/USB1.D+: R3.1, U2.52 (USB_DP)
/USB1.D-: R4.1, U2.51 (USB_DM)
/USB2.D+: R17.1, U2.16 (GPIO12)
/USB2.D-: R18.1, U2.17 (GPIO13)
/VREG_AVDD: C10.1, R1.2, U2.46 (VREG_AVDD)
/VREG_LX: L1.2, U2.48 (VREG_LX)
GND: C1.2, C2.2, C3.2, C4.1, C5.1, C6.2, C7.2, C8.2, C9.2, C10.2, C11.2, C12.2, C13.2, C14.2, C15.2, C16.2, C17.2, C18.2, C19.2, D1.1 (K), D2.1 (K), J1.2, J1.MP (MountPin), SW1.1, U1.1 (GND), U2.47 (VREG_PGND), U2.61 (GND), Y1.2, Y1.4; also elsewhere on the board
MIDI_IN_UART_RX: U2.8 (GPIO5); also elsewhere on the board
MIDI_OUT_UART_TX: U2.7 (GPIO4); also elsewhere on the board
unnamed: D1.2 (A), R5.1
unnamed: D2.2 (A), R6.1
unnamed: J1.1, U2.24 (SWCLK)
unnamed: J1.3, U2.25 (SWD)
unnamed: R2.1, SW1.2
unnamed: R2.2, U2.26 (RUN)
unnamed: R16.1, U2.22 (XOUT)
USB1_ESD.D+: R3.2; also elsewhere on the board
USB1_ESD.D-: R4.2; also elsewhere on the board
USB2_ESD.D+: R17.2; also elsewhere on the board
USB2_ESD.D-: R18.2; also elsewhere on the board
VBUS: C2.1, U1.3 (VI); also elsewhere on the board

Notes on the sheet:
Place capacitors close to regulator
Place 27R resistors close to MCU pins.
5V to 3.3V Power Regulator
Max 1.2A output current 2.5V < Vin < 18V 350mV dropout at 1.2A
Debug Header
Reset/Boot Select Button
See page 448 of RP2350 Datasheet and page 7 of Hardware Design Guide for PCB layout guidelines for high switching current paths
User LEDs
Internal Power Regulator
Crystal
Only use ABM8-272-T3 crystal. Place capacitors close to crystal.


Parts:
C20: 100nF; C_0402_1005Metric_small_pads; Part Number CL05B104KB54PNC; LCSC C307331
C21: 100nF; C_0603; Part Number CC0603KRX7R9BB104; LCSC C14663
C22: 10uF; C_0603; Part Number CL10A106MA8NRNC; LCSC C96446
C23, C24, C25: 47uF; C_1206_3216Metric; Part Number CL31A476MPHNNNE; LCSC C96123
J2: USB_C_Receptacle_USB2.0_16P; USB_C_Receptacle_HRO_TYPE-C-31-M-12_Overhanging; Part Number TYPE-C-31-M-12; LCSC C165948
J3: USB_C_Receptacle_USB2.0_14P; USB_C_Receptacle_HRO_TYPE-C-31-M-12_Overhanging; Part Number TYPE-C-31-M-12; LCSC C165948
J4, J5: TRS; Jack_3.5mm_KoreanHropartsElec_PJ-320D-4A_Horizontal_Overhan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; Part Number PJ-320D-4A; LCSC C95562
R7, R8: 5.1K; R_0603; Part Number 0603WAF5101T5E; LCSC C23186
R11: 33R; R_0402_1005Metric; Part Number 0402WGF330JTCE; LCSC C25105
R12: 10R; R_0402_1005Metric; Part Number 0402WGF100JTCE; LCSC C25077
R13, R14: 220R; R_0402_1005Metric; Part Number 0402WGF2200TCE; LCSC C25091
R15: 470R; R_0402_1005Metric; Part Number 0402WGF4700TCE; LCSC C25117
R19: 100K; R_0402_1005Metric; Part Number 0402WGF1003TCE; LCSC C25741
U3, U4: USBLC6-2SC6; SOT-23-6; Part Number USBLC6-2SC6; LCSC C7519
U5: HCPL-0631; SOIC-8_3.9x4.9mm_P1.27mm; Part Number HCPL-0631-500E; LCSC C43949
U6: TPS25810RVC; Texas_RVC0020A_WQFN-20-1EP_3x4mm_P0.5mm_EP1.6x2.6mm_Thermal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; Part Number TPS25810RVCR; LCSC C473913

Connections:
+3V3: R11.2, R15.2; also elsewhere on the board
/Connectors/HOST_VBUS_OUT: C22.1, J3.A4 (VBUS), J3.A9 (VBUS), J3.B4 (VBUS), J3.B9 (VBUS), U4.5 (VBUS), U6.14 (OUT), U6.15 (OUT)
/Connectors/USB1.CC1: J2.A5 (CC1), R7.1
/Connectors/USB1.CC2: J2.B5 (CC2), R8.1
/Connectors/USB1_CONN.D+: J2.A6 (D+), J2.B6 (D+), U3.4 (I/O2)
/Connectors/USB1_CONN.D-: J2.A7 (D-), J2.B7 (D-), U3.6 (I/O1)
/Connectors/USB2_CONN.D+: J3.A6 (D+), J3.B6 (D+), U4.4 (I/O2)
/Connectors/USB2_CONN.D-: J3.A7 (D-), J3.B7 (D-), U4.6 (I/O1)
GND: C20.2, C21.2, C22.2, C23.2, C24.2, C25.2, J2.A1 (GND), J2.A12 (GND), J2.B1 (GND), J2.B12 (GND), J2.S1 (SHIELD), J3.A1 (GND), J3.A12 (GND), J3.B1 (GND), J3.B12 (GND), J3.S1 (SHIELD), J5.G, J5.S, R7.2, R8.2, U3.2 (GND), U4.2 (GND), U5.5 (GND), U6.7 (CHG), U6.8 (CHG_HI), U6.12 (GND), U6.21 (GND); also elsewhere on the board
MIDI_IN_UART_RX: R15.1, U5.6 (VO2), U5.7 (VO1); also elsewhere on the board
MIDI_OUT_UART_TX: R12.1; also elsewhere on the board
unnamed: C20.1, J4.G, J4.S
unnamed: J3.A5 (CC1), U6.11 (CC1)
unnamed: J3.B5 (CC2), U6.13 (CC2)
unnamed: J5.R, R11.1
unnamed: J5.T, R12.2
unnamed: R13.2, U5.1 (A1)
unnamed: R14.2, U5.4 (A2)
unnamed: J4.T, R14.1, U5.2 (C1)
unnamed: J4.R, R13.1, U5.3 (C2)
unnamed: R19.1, U6.10 (REF)
unnamed: R19.2, U6.9 (REF_RTN)
USB1_ESD.D+: U3.3 (I/O2); also elsewhere on the board
USB1_ESD.D-: U3.1 (I/O1); also elsewhere on the board
USB2_ESD.D+: U4.3 (I/O2); also elsewhere on the board
USB2_ESD.D-: U4.1 (I/O1); also elsewhere on the board
VBUS: C21.1, C23.1, C24.1, C25.1, J2.A4 (VBUS), J2.A9 (VBUS), J2.B4 (VBUS), J2.B9 (VBUS), U3.5 (VBUS), U5.8 (VCC), U6.2 (IN1), U6.3 (IN1), U6.4 (IN2), U6.5 (AUX), U6.6 (EN); also elsewhere on the board

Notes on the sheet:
CHG and CHG_HI both pulled low broadcasting standard USB current capabillity and limiting current draw to 1.7A
MIDI Out
10uF near connector
MIDI In
USB data differential pairs should be impedance matched to 90 ohms.
MIDI 1.0 Electrical Specification Update (for 3.3V compatibility https://drive.google.com/file/d/1L2YHBOZdSCuMg-RFR3TTEJcdV6KWkLZ9/view
MIDI TRS
Close to IC pins
Specification for use of TRS Connectors with MIDI Devices https://drive.google.com/file/d/1Eb93WQkEv1YaUp8N3ph6Fq5HtOFCnT88/view
USB Host Port
LPZW auto-crossover MIDI input schematic Thanks to Kay Knofe, LPZW Modules https://leipzigwest.org/?page_id=2
USB Device Port


Board: 4 copper layers, 51.0 x 32.0 mm, 60 parts (0 on the bottom side), 45 nets.

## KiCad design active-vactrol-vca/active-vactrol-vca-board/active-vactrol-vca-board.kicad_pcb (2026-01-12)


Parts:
C1, C2: 10uF_0805_25V; C_0805; Part Number GRM21BR61H106KE43L; LCSC C440198
C3, C6: 22uF_0805_25V; C_0805; Part Number CL21A226MAQNNNE; LCSC C45783
D1, D2: Schottky; D_SMA_Handsoldering; Part Number SS34; LCSC C8678
L1, L2: FerriteBead_0603_2A; R_0603; Part Number BLM18PG121SN1D; LCSC C14709
PWR1: Eurorack_Power; Eurorack_Power_Shrouded_TH_Staggered_Small
R6, R7: 1R; R_0603; Part Number 0603WAF100KT5E; LCSC C22936
U1, U2, U3, U4: TL072; SOIC-8_3.9x4.9mm_P1.27mm; Part Number TL072CDT; LCSC C6961
U7: AMS1117-5.0; SOT-223-3_TabPin2; Part Number AMS1117-5.0; LCSC C6187

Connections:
+5V: R7.1, U7.2 (VO); also elsewhere on the board
+12V: C2.1, D1.1 (K), R6.1, U1.8 (V+), U2.8 (V+), U3.8 (V+), U4.8 (V+), U7.3 (VI)
-12V: C1.1, D2.2 (A), U1.4 (V-), U2.4 (V-), U3.4 (V-), U4.4 (V-)
/+12V_In: L1.1, PWR1.9 (+12V), PWR1.10 (+12V)
/-12V_In: L2.1, PWR1.1 (-12V), PWR1.2 (-12V)
GND: C1.2, C2.2, C3.1, C6.1, PWR1.3 (GND), PWR1.4 (GND), PWR1.5 (GND), PWR1.6 (GND), PWR1.7 (GND), PWR1.8 (GND), U7.1 (GND); also elsewhere on the board
unnamed: C3.2, R6.2
unnamed: C6.2, R7.2
unnamed: D1.2 (A), L1.2
unnamed: D2.1 (K), L2.2

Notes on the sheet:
1R series resistor with bypass capacitors help provide regulator stability.
Note, in paults' schematic, the ferrite bead he uses is a Murata BLM21PG221SN1D which is 220R@100MHz. This part (120R@100MHz) is substituted because it's JLC Basic, but may not be as suitable a part. He also specifies STM STPS1L30U for the Schottky diode, which has been substituted here for a JLC b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
Power circuit from Paul Schreiber.
+12V/-12V Rails

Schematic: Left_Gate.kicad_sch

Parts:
C4: 0.1uF film; C_Rect_L7.2mm_W2.5mm_P5.00mm_FKS2_FKP2_MKS2_MKP2
C5: 33pF C0G; C_0603; Part Number CL10C330JB8NNNC; LCSC C1663
J1, J2, J3: Thonkiconn_Mono_Audio_Jack; Audio_Jack_Thonkiconn_Mono_Left_Overhang; Part Number WQP518MA/PJ398SM
R1, R2, R3, R4, R5, R8, R20: 100k_0603; R_0603; Part Number 0603WAF1003T5E; LCSC C25803
R9: 1k_0603; R_0603; Part Number 0603WAF1001T5E; LCSC C21190
RV1: B10K; Potentiometer_Alpha_RD901_Eurorack; Part Number RD901F-40
U1, U2: TL072; SOIC-8_3.9x4.9mm_P1.27mm; Part Number TL072CDT; LCSC C6961
U5: NSL-32R3 60R@20mA; NSL-32

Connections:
+5V: R5.1; also elsewhere on the board
/Left Gate/L_BUFFERED: R4.2, U1.7, U5.3 (R)
/Left Gate/L_CV_ATTENUATED: RV1.2, U5.2 (K)
/Left Gate/L_CV_BUFFERED: R2.2, RV1.3, U1.1
/Left Gate/L_IN_UNBUFFERED: J2.T, R3.1
/Left Gate/L_VACTROL_OUTPUT: C4.1, U2.3 (+), U5.4 (R)
GND: C4.2, J1.S, J2.S, J3.S, RV1.1, U1.3 (+), U1.5 (+), U2.5 (+), U5.1 (A); also elsewhere on the board
L_CV_INPUT: J1.T, R1.1; also elsewhere on the board
L_OUTPUT: C5.1, J3.T, R8.2, R9.2; also elsewhere on the board
unnamed: J1.TN, R5.2
unnamed: R9.1, U2.7
unnamed: R1.2, R2.1, U1.2 (-)
unnamed: R3.2, R4.1, U1.6 (-)
unnamed: R20.1, U2.1, U2.2 (-)
unnamed: C5.2, R8.1, R20.2, U2.6 (-)

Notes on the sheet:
Unity gain buffer, 100k input impedance.
NSL-32SR3 resistance @ 20mA is 60R max cutoff frequency is: 0.1uF = 26.5KHz @ 20mA, 10.6KHz @ 5mA 0.15uF = 16.7KHz @ 20mA, 7.1KHz @ 5mA 0.22uF = 12.1Hz @ 20mA, 4.8KHz @ 5mA 0.47uF = 5.6KHz @ 20mA, 2.3KHz @ 5mA
Unity gain buffer, 1k output inpedance. Op amp feedback filter 48.2KHz cutoff
Vactrol LED connection is backwards, because the CV has been inverted.
CV attuenuator

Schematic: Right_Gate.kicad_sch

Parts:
C7: 0.1uF film; C_Rect_L7.2mm_W2.5mm_P5.00mm_FKS2_FKP2_MKS2_MKP2
C8: 33pF C0G; C_0603; Part Number CL10C330JB8NNNC; LCSC C1663
J4, J5, J6: Thonkiconn_Mono_Audio_Jack; Audio_Jack_Thonkiconn_Mono_Right_Overhang; Part Number WQP518MA/PJ398SM
R10, R11, R12, R13, R17, R19: 100k_0603; R_0603; Part Number 0603WAF1003T5E; LCSC C25803
R18: 1k_0603; R_0603; Part Number 0603WAF1001T5E; LCSC C21190
RV2: B10K; Potentiometer_Alpha_RD901_Eurorack; Part Number RD901F-40
U3, U4: TL072; SOIC-8_3.9x4.9mm_P1.27mm; Part Number TL072CDT; LCSC C6961
U6: NSL-32R3 60R@20mA; NSL-32

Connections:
/Right Gate/R_BUFFERED: R13.2, U3.7, U6.3 (R)
/Right Gate/R_CV_ATTENUATED: RV2.2, U6.2 (K)
/Right Gate/R_CV_BUFFERED: R11.2, RV2.3, U3.1
/Right Gate/R_CV_IN_UNBUFFERED: J4.T, R10.1
/Right Gate/R_IN_UNBUFFERED: J5.T, R12.1
/Right Gate/R_OUT_BUFFERED: C8.1, J6.T, R17.2, R18.2
/Right Gate/R_VACTROL_OUTPUT: C7.1, U4.3 (+), U6.4 (R)
GND: C7.2, J4.S, J5.S, J6.S, RV2.1, U3.3 (+), U3.5 (+), U4.5 (+), U6.1 (A); also elsewhere on the board
L_CV_INPUT: J4.TN; also elsewhere on the board
L_OUTPUT: J5.TN; also elsewhere on the board
unnamed: R18.1, U4.7
unnamed: R10.2, R11.1, U3.2 (-)
unnamed: R12.2, R13.1, U3.6 (-)
unnamed: R19.1, U4.1, U4.2 (-)
unnamed: C8.2, R17.1, R19.2, U4.6 (-)

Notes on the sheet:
CV attuenuator
Unity gain buffer, 100k input impedance.
NSL-32SR3 resistance @ 20mA is 60R max cutoff frequency is: 0.1uF = 26.5KHz @ 20mA, 10.6KHz @ 5mA 0.15uF = 16.7KHz @ 20mA, 7.1KHz @ 5mA 0.22uF = 12.1Hz @ 20mA, 4.8KHz @ 5mA 0.47uF = 5.6KHz @ 20mA, 2.3KHz @ 5mA
Unity gain buffer, 1k output inpedance. Op amp feedback filter 48.2KHz cutoff



Board: 2 copper layers, 19.0 x 108.0 mm, 45 parts (35 on the bottom side), 35 nets.

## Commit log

2024-05-10 First commit of LCS's eurorack module hardware designs.
    [2 hp usb extender.dxf, edge cuts - 2 hp usb extender.dxf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]
2024-05-10 Renames a couple of module directories.
    [2 hp usb extender.dxf, edge cuts - 2 hp usb extender.dxf, silkscreen - 2 hp usb extender.dxf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]
2024-05-10 Updates Patch SM boards to non-exploding footprint.
    [lichen-bifocals-submodule-power-board.kicad_pcb, lichen-dev-module.kicad_pcb, simplest-patchsm-module.kicad_pcb]
2024-05-10 Fixes connections between jacks and switches on Lichen Sw. Now the panel is laid out so channels 1-3 are laid out sequentially.
    [lichen-passive-mutes-board.kicad_pcb, lichen-passive-mutes-board.kicad_sch]
2024-09-01 v1.1 of Freddie and Bifocals hardware.
    [lichen-bifocals-control-board.kicad_pcb, lichen-bifocals-control-board.kicad_sch, lichen-bifocals-panel.kicad_pcb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]
2024-10-25 Updates Lichen component library and most module prototypes.
    [lichen-bifocals-bom.xlsx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]
2024-10-31 Scales Lichen Four CV outputs to -8V to 8V to match audio outputs.
    [lichen-four-board.kicad_pcb, lichen-four-board.kicad_sch]
2025-09-14 Updates to Lichen symbols and footpints; adds RP2350 blocks.
    [rp2350-eurorack-building-blocks.kicad_pcb, rp2350-eurorack-building-blocks.kicad_sch]
2025-12-14 Updates KiCad symbols and footprints. Adds vactrol VCA.
    [BOM-active-vactrol-vca-board.csv, BOM-active-vactrol-vca-panel.csv, Left_Gate.kicad_sch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]
2025-12-17 Adds v1.0 of Crustose and updates Vactrol VCA for production. Updates Lichen symbol and footprint library..
    [Amplifiers.kicad_sch, BOM-active-vactrol-vca-board.csv, BOM-lichen-crustose-control-board.csv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]
2025-12-17 Adds design blocks.
    [Basic 5V Regulator.kicad_sch, Basic Analog Eurorack Power.kicad_sch, Buffered Input.kicad_sch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]
2025-12-30 Adds RP2350-based MIDI transformer, breadboard adaptors, and new design blocks.
    [BOM-lichen-breadboard-alpha-pot-dual-adaptor.csv, BOM-lichen-breadboard-alpha-pot-single-adaptor.csv, BOM-lichen-breadboard-spdt-switch-adaptor.csv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]
2026-01-12 Updates Lichen symbols and footprints. Fixes to Crustose and Vactrol VCA. Adds 3D model of the RP2350 dual USB board.
    [5V Fixed Boost Regulator.kicad_sch, Amplifiers.kicad_sch, AnalogInputs.kicad_sch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]
2026-01-12 Adds STEP file for rp2350 dual USB board.
2026-01-18 Updates YouMe Transformer to v1.1, fixing incorrect R10 value. Improves the consistency of the Lichen symbol library.
    [Connectors.kicad_sch, rp2350-dual-usb.kicad_pcb, rp2350-dual-usb.kicad_sch]
2026-03-04 feat: Updates symbol libraries and design blocks. Adds in-progress RP2350-based module.
    [3V3 Buck-Boost Regulator TPS63031.kicad_sch, Audio_IO.kicad_sch, Connectors.kicad_sch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]
2026-03-05 feat: Adds NSL-33 dual vactrol symbol and footprint.
2026-03-17 Updates symbols, footprints, and design blocks.
    [Eurorack Power - All JLC Basic.kicad_sch, Eurorack_Power.kicad_sch, Stereo Moritz Klein Diode Ladder LPF.kicad_sch]
2026-03-17 Updates YouMe Transformer to v1.2, adds USB host management IC.
    [Connectors.kicad_sch, rp2350-dual-usb.kicad_pcb]
2026-03-17 Adds in-progress stereo LPF based on Moritz Klein's design.
    [lichen-stereo-klein-filter-board.kicad_pcb, lichen-stereo-klein-filter-board.kicad_sch, lichen-stereo-klein-filter-controls.kicad_pcb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]
2026-04-07 feat: Updates Crustose, Cladonia and YouMe Transformer. Adds Stereo Latencies.
    [Amplifiers.kicad_sch, BOM-lichen-crustose-control-board.csv, BOM-lichen-crustose-processing-board.csv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]
2026-04-20 fix: Uses correct VQFN-16 footprint. feat: Adds pin header version of Pico debugging port.

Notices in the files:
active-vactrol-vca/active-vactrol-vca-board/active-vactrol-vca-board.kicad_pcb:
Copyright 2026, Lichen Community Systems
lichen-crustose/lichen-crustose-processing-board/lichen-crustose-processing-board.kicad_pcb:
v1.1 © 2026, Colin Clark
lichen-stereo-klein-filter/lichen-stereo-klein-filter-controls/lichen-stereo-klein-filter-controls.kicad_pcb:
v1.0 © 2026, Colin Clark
